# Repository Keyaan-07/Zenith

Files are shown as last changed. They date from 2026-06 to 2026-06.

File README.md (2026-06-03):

# Zenith

Zenith is a small single board computer made with the RK3328 which comes with 512 MegaBytes of DDR3 RAM. Zenith is built to run on battery backups along with USB Type-C power inputs. Features of zenith are:  

- Quad core ARM Cortex-A53 CPU
- 512 MB DDR3 RAM
- SD support
- 100M ethernet
- HDMI out
- 24 bit audio
- 1x USB 3.0 2x USB 2.0

I made this SBC because i wanted to locally host some slack bots. There is literally no other reason. I have not compiled buildroot because i'll be using a prebuilt version from ROCK64. A small reason for this is because my laptop probably cannot handle compiling linux. 

Check out this project on [KiCanvas](https://kicanvas.org/?repo=https%3A%2F%2Fgithub.com%2FKeyaan-07%2FZenith%2Ftree%2Fmain%2Fhardware)!  
To check schematics, please go to the above link, imaging every page and putting it here would clutter the README.

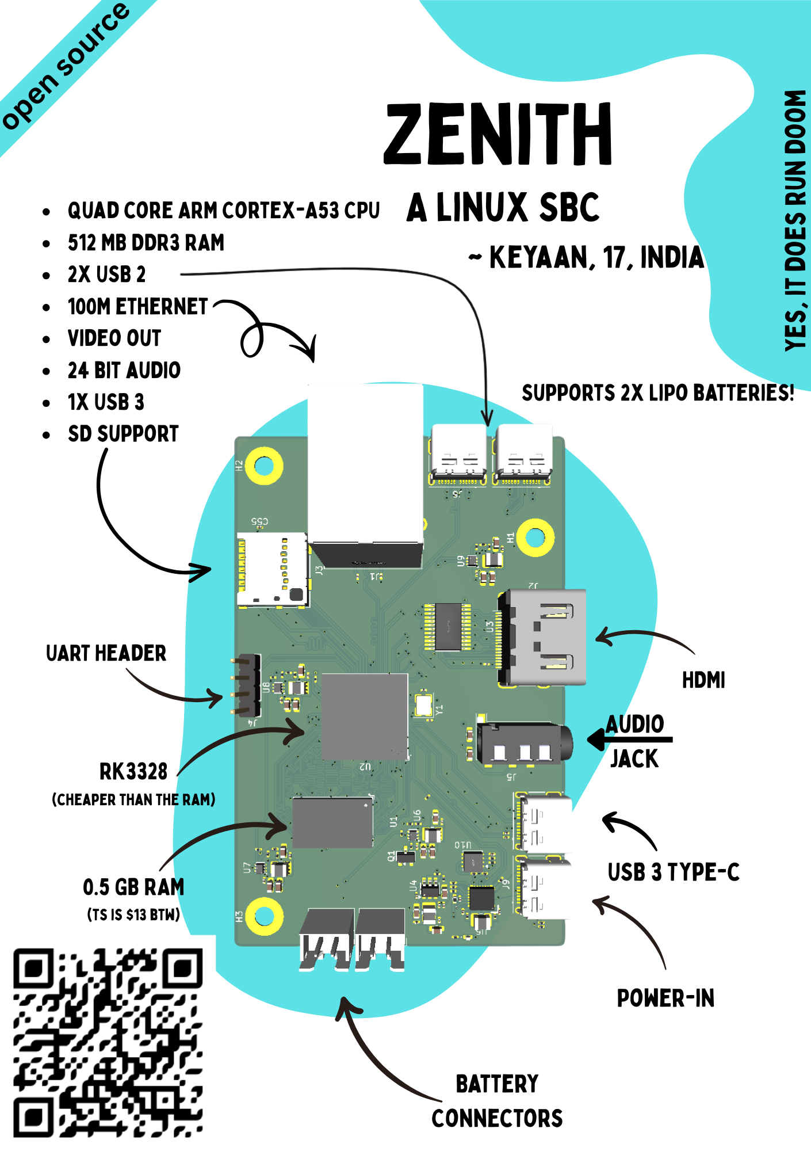
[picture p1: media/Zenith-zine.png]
zine

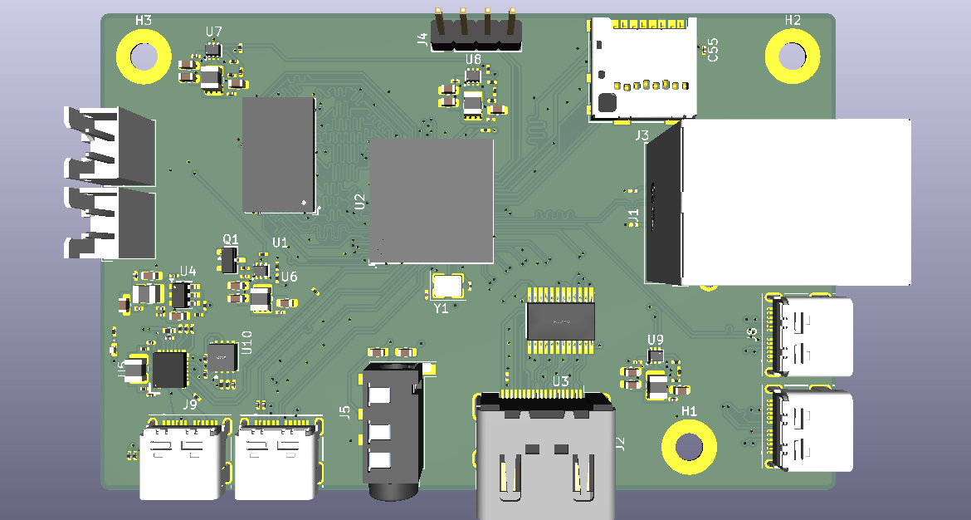
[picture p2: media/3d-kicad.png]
kicad-render

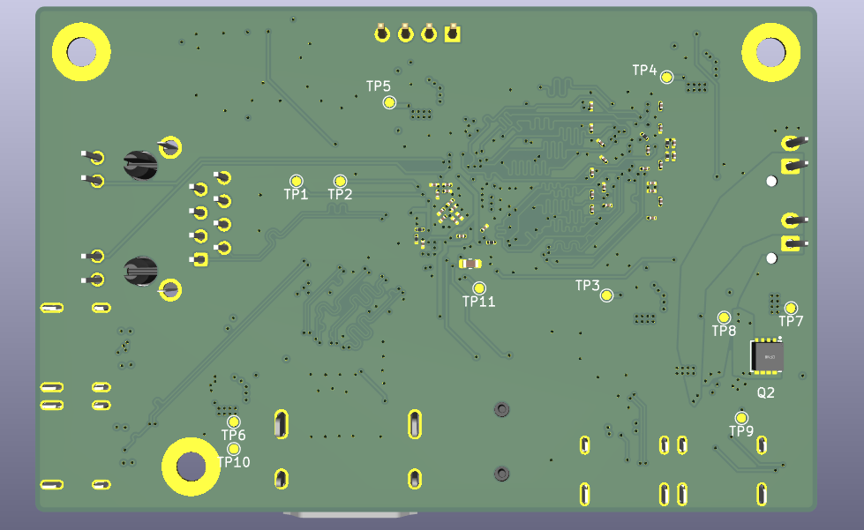
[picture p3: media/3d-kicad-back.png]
kicad-render-back

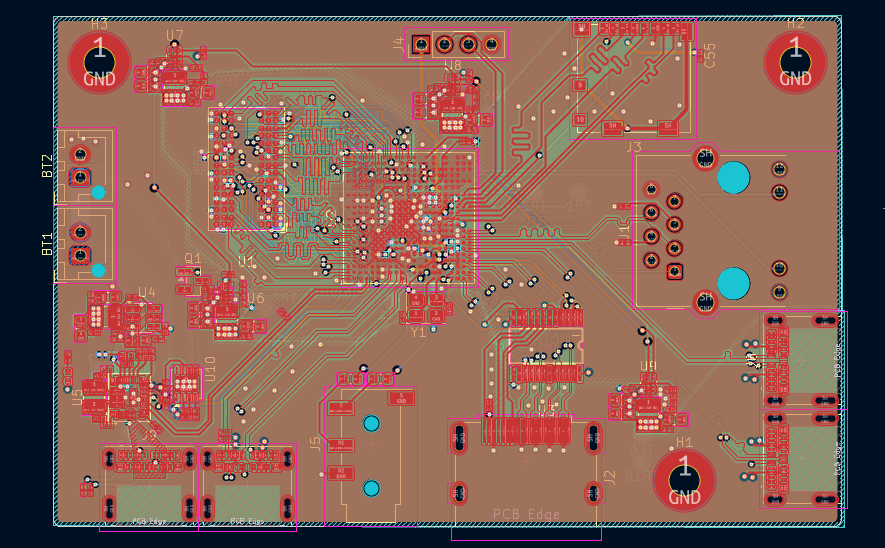
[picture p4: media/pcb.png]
kicad


## Assembly guide:  
1. clone the repo and head to production: 
```bash
git clone https://Github.com/Keyaan-07/Zenith
cd Zenith/hardware/production
```
2. go to your preferred PCB manufacturer and upload the gerber files there. 
3. get the PCBA option for both(or one) sides.
4. Build the firmware from the [buildroot](https://github.com/buildroot/buildroot) repo.
5. flash it to the SD card using [rufus.ie](https://rufus.ie)
6. plug the SD card in and start the board. 

# BOM

|Designator |Function |Value |Quantity|Price |Amount  |Link |
|---|---|---|---|---|---|---|
|PCB |PCB |85x55mm |5 |9.6 |48 |https://jlcpcb.com/ |
|PCBA |Standard |PCBA |2 |42.75 |85.5 |https://jlcpcb.com/ |
|BT1, BT2 |Battery Connectors|Battery_Cell |4 | |0 | |
|C0, C1, C10, C11, C12, C13, C14, C15, C16, C17, C18, C19, C2, C21, C22, C23, C24, C25, C26, C27, C28, C29, C3, C30, C31, C32, C33, C35, C37, C4, C40, C42, C47, C48, C5, C51, C52, C53, C54, C55, C58, C6, C62, C64, C67, C7, C70, C71, C74, C75, C8, C9|Capacitor |100n |104 |0.001 |0.104 |https://www.lcsc.com/product-detail/C49062.html |
|C20, C34, C36, C38, C39, C41, C43, C44, C45, C46, C49, C50, C56, C57, C59, C63, C66 |Capacitor |10u |34 |0.03  |1.02 |https://www.lcsc.com/product-detail/C96446.html |
|C60, C61 |Capacitor |15p |4 |0.0013|0.0052  |https://www.lcsc.com/product-detail/C277480.html  |
|C65, C68 |Capacitor |1u |4 |0.009 |0.036 |https://www.lcsc.com/product-detail/C307385.html  |
|C72, C73 |Capacitor |47n |4 |0.0044|0.0176  |https://www.lcsc.com/product-detail/C2930549.html |
|D1 |LED |LED |2 |0.009 |0.018 |https://www.lcsc.com/product-detail/C7496805.html |
|J1 |Ethernet magjack  |- |2 |1.5 |3 |https://www.lcsc.com/product-detail/C12074.html |
|J2 |HDMI |- |2 |1.5 |3 |https://www.lcsc.com/product-detail/C916313.html  |
|J3 |Micro SD Connector|- |2 |0.68  |1.36 |https://www.lcsc.com/product-detail/C585350.html  |
|J4 |UART header |- |2 |DNP |DNP |DNP |
|J5 |Audiojack |- |2 |0.05  |0.1 |https://www.lcsc.com/product-detail/C431535.html  |
|J6, J7, J8, J9 |USB-C |- |8 |0.5 |4 |https://www.lcsc.com/product-detail/C5156605.html |
|L1, L2, L3, L4, L5, L6 |Inductors |2.2u |12 |0.03  |0.36 |https://www.lcsc.com/product-detail/C45385204.html|
|Q1 |MOSFET |2N7002 |2 |0.05  |0.1 |https://www.lcsc.com/product-detail/C81445.html |
|Q2 |MOSFET |AON7262e |2 |0.58  |1.16 |https://www.lcsc.com/product-detail/C176755.html  |
|R1 |Resistor |240 |2 |0.0009|0.0018  |https://www.lcsc.com/product-detail/C270354.html  |
|R11, R17, R2, R26, R27, R3, R30, R31, R32, R33, R35, R38, R40, R5, R6, R8, R9 |Resistor |10k |34 |0.0007|0.0238  |https://www.lcsc.com/product-detail/C7467266.html |
|R12, R41 |Resistor |35k |4 |0.0015|0.006 |https://www.lcsc.com/product-detail/C180320.html  |
|R13, R14, R15, R18, R19, R20 |Resistor |R |12 |- |0 |- |
|R16 |Resistor |56k |2 |0.0008|0.0016  |https://www.lcsc.com/product-detail/C18164325.html|
|R21 |Resistor |10m |2 |0.14  |0.28 |https://www.lcsc.com/product-detail/C6250315.html |
|R22, R23, R24, R25, R34 |Resistor |100 |10 |0.0009|0.009 |https://www.lcsc.com/product-detail/C270366.html  |
|R28, R29 |Resistor |0R |4 |0.0009|0.0036  |https://www.lcsc.com/product-detail/C106228.html  |
|R36, R37, R39 |Resistor |5.1k |6 |0.0007|0.0042  |https://www.lcsc.com/product-detail/C7467269.html |
|R4 |Resistor |6.6k |2 |0.0008|0.0016  |https://www.lcsc.com/product-detail/C423452.html  |
|U1 |RAM |NT5CB256M16ER-FL|2 |13.15 |26.3 |https://www.lcsc.com/product-detail/C2841154.html |
|U10 |SoC |BQ29209DRBR |2 |0.76  |1.52 |https://www.lcsc.com/product-detail/C139352.html  |
|U2 |main IC |RK3328 |2 |8.65  |17.3 |https://www.lcsc.com/product-detail/C2932939.html |
|U3 |ESD IC for HDMI |TPD12S016PWR |2 |0.8382|1.6764  |https://www.lcsc.com/product-detail/C201665.html  |
|U4 |Buck |TPS565201 |2 |0.64  |1.28 |https://www.lcsc.com/product-detail/C327676.html  |
|U5 |Battery charger |BQ25690RBAR |2 |6.3 |12.6 |https://www.lcsc.com/product-detail/C53283868.html|
|U6, U7, U8, U9 |Buck |TPS563252DRLR |8 |1.05  |8.4 |https://www.lcsc.com/product-detail/C19188399.html|
|Y1 |Crystal |24MHz |2 |0.58  |1.16 |https://www.lcsc.com/product-detail/C41383245.html|
| | | | | | | |
| | | | | | | |
| | | | | | | |
| | | | | |134.8488| |

### Onshape link
[here](https://cad.onshape.com/documents/332461f2f869658015d1b4b3/w/bc37113696b38b58a706d278/e/a246ca9cc7cf7bf594e6cd93) is the onshape link for the project

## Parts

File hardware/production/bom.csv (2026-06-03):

Designator | Footprint | Quantity | Value | LCSC Part #
BT1, BT2 | JST_XH_B2B-XH-AM_1x02_P2.50mm_Vertical | 2 | Battery_Cell
C0, C1, C10, C11, C12, C13, C14, C15, C16, C17, C18, C19, C2, C21, C22, C23, C24, C25, C26, C27, C28, C29, C3, C30, C31, C32, C33, C35, C37, C4, C40, C42, C47, C48, C5, C51, C52, C53, C54, C55, C58, C6, C62, C64, C67, C7, C70, C71, C74, C75, C8, C9 | 0201 | 52 | 100n
C20, C34, C36, C38, C39, C41, C43, C44, C45, C46, C49, C50, C56, C57, C59, C63, C66 | 0603 | 17 | 10u
C60, C61 | 0201 | 2 | C_Small
C65, C68 | 0201 | 2 | 1u
C69 | 0603 | 1 | 22u
C72, C73 | 0201 | 2 | 47n
D1 | 0402 | 1 | LED
J1 | RJ45_Hanrun_HR911105A_Horizontal | 1 | RJ45_Hanrun_HR911105A_Horizontal
J2 | HDMI_A_Molex_208658-1001_Horizontal | 1 | HDMI_A
J3 | microSD_HC_Molex_104031-0811 | 1 | Micro_SD_Card
J4 | PinHeader_1x04_P2.54mm_Vertical | 1 | Conn_01x04_Pin
J5 | Jack_3.5mm_KoreanHropartsElec_PJ-320D-4A_Horizontal | 1 | AudioJack4
J6, J7, J8, J9 | USB_C_Receptacle_Molex_105450-0101 | 4 | USB_C_Receptacle
L1, L2, L3, L4, L5, L6 | 1008 | 6 | 2.2u
Q1 | SOT-23 | 1 | 2N7002
Q2 | DFN-8_L3.3-W3.3-P0.65-BL | 1 | AON7262e | C176755
R1 | 0201 | 1 | 240
R11, R17, R2, R26, R27, R3, R30, R31, R32, R33, R35, R38, R40, R5, R6, R8, R9 | 0201 | 17 | 10k
R12, R41 | 0201 | 2 | 35k
R13, R14, R15, R18, R19, R20 | 0201 | 6 | R
R16 | 0201 | 1 | 56k
R21 | 0402 | 1 | 10m
R22, R23, R24, R25, R34 | 0201 | 5 | 100
R28, R29 | 0201 | 2 | 0R
R36, R37, R39 | 0201 | 3 | 5.1k
R4 | 0201 | 1 | 6.6k
TP1 | TestPoint_Pad_D1.0mm | 1 | ~{UART0_CTS}
TP10, TP11, TP3, TP4, TP5, TP6, TP7, TP8, TP9 | TestPoint_Pad_D1.0mm | 9 | TestPoint
TP2 | TestPoint_Pad_D1.0mm | 1 | ~{UART0_RST}
U1 | TFBGA-96_L13.0-W8.0-R16-C6-P0.80-TL | 1 | NT5CB256M16ER-FL | C2841154
U10 | VSON-8-1EP_3x3mm_P0.65mm_EP1.6x2.4mm | 1 | BQ29209DRBR | C139352
U2 | TFBGA395_L14.0-W14.0_RK3328 | 1 | RK3328 | C2932939
U3 | TSSOP-24_L7.8-W4.4-P0.65-LS6.4-BL | 1 | TPD12S016PWR | C201665
U4 | SOT-23-6 | 1 | TPS565201
U5 | WQFN-26_L4.0-W3.5_BQ25690RBAR | 1 | BQ25690RBAR | C53283868
U6, U7, U8, U9 | SOT-563-6_L1.6-W1.2-P0.50-LS1.6-BL | 4 | TPS563252DRLR | C19188399
Y1 | Crystal_SMD_3225-4Pin_3.2x2.5mm | 1 | Crystal_GND24

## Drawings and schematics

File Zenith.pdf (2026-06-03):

# Zenith

# A linux SBC

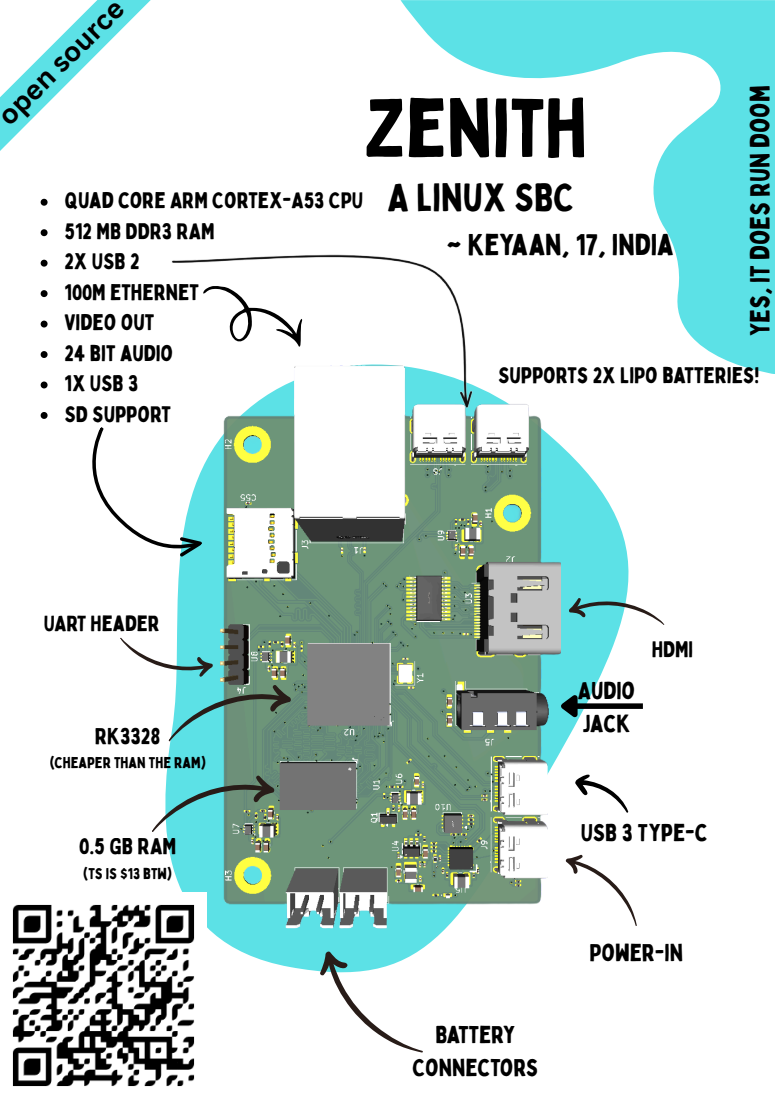
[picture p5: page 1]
Audio jack; ~ Keyaan, 17, india; open source; Battery Connectors; Power-in; USB 3 Type-c; UART Header; HDMI

Quad core ARM Cortex-A53 CPU
512 MB DDR3 RAM
2x USB 2
100M ethernet
Video out
24 bit audio
1x USB 3
SD support

Supports 2x LiPo batteries!

(cheaper than the ram)

0.5 GB RAM
(ts is $13 btw)

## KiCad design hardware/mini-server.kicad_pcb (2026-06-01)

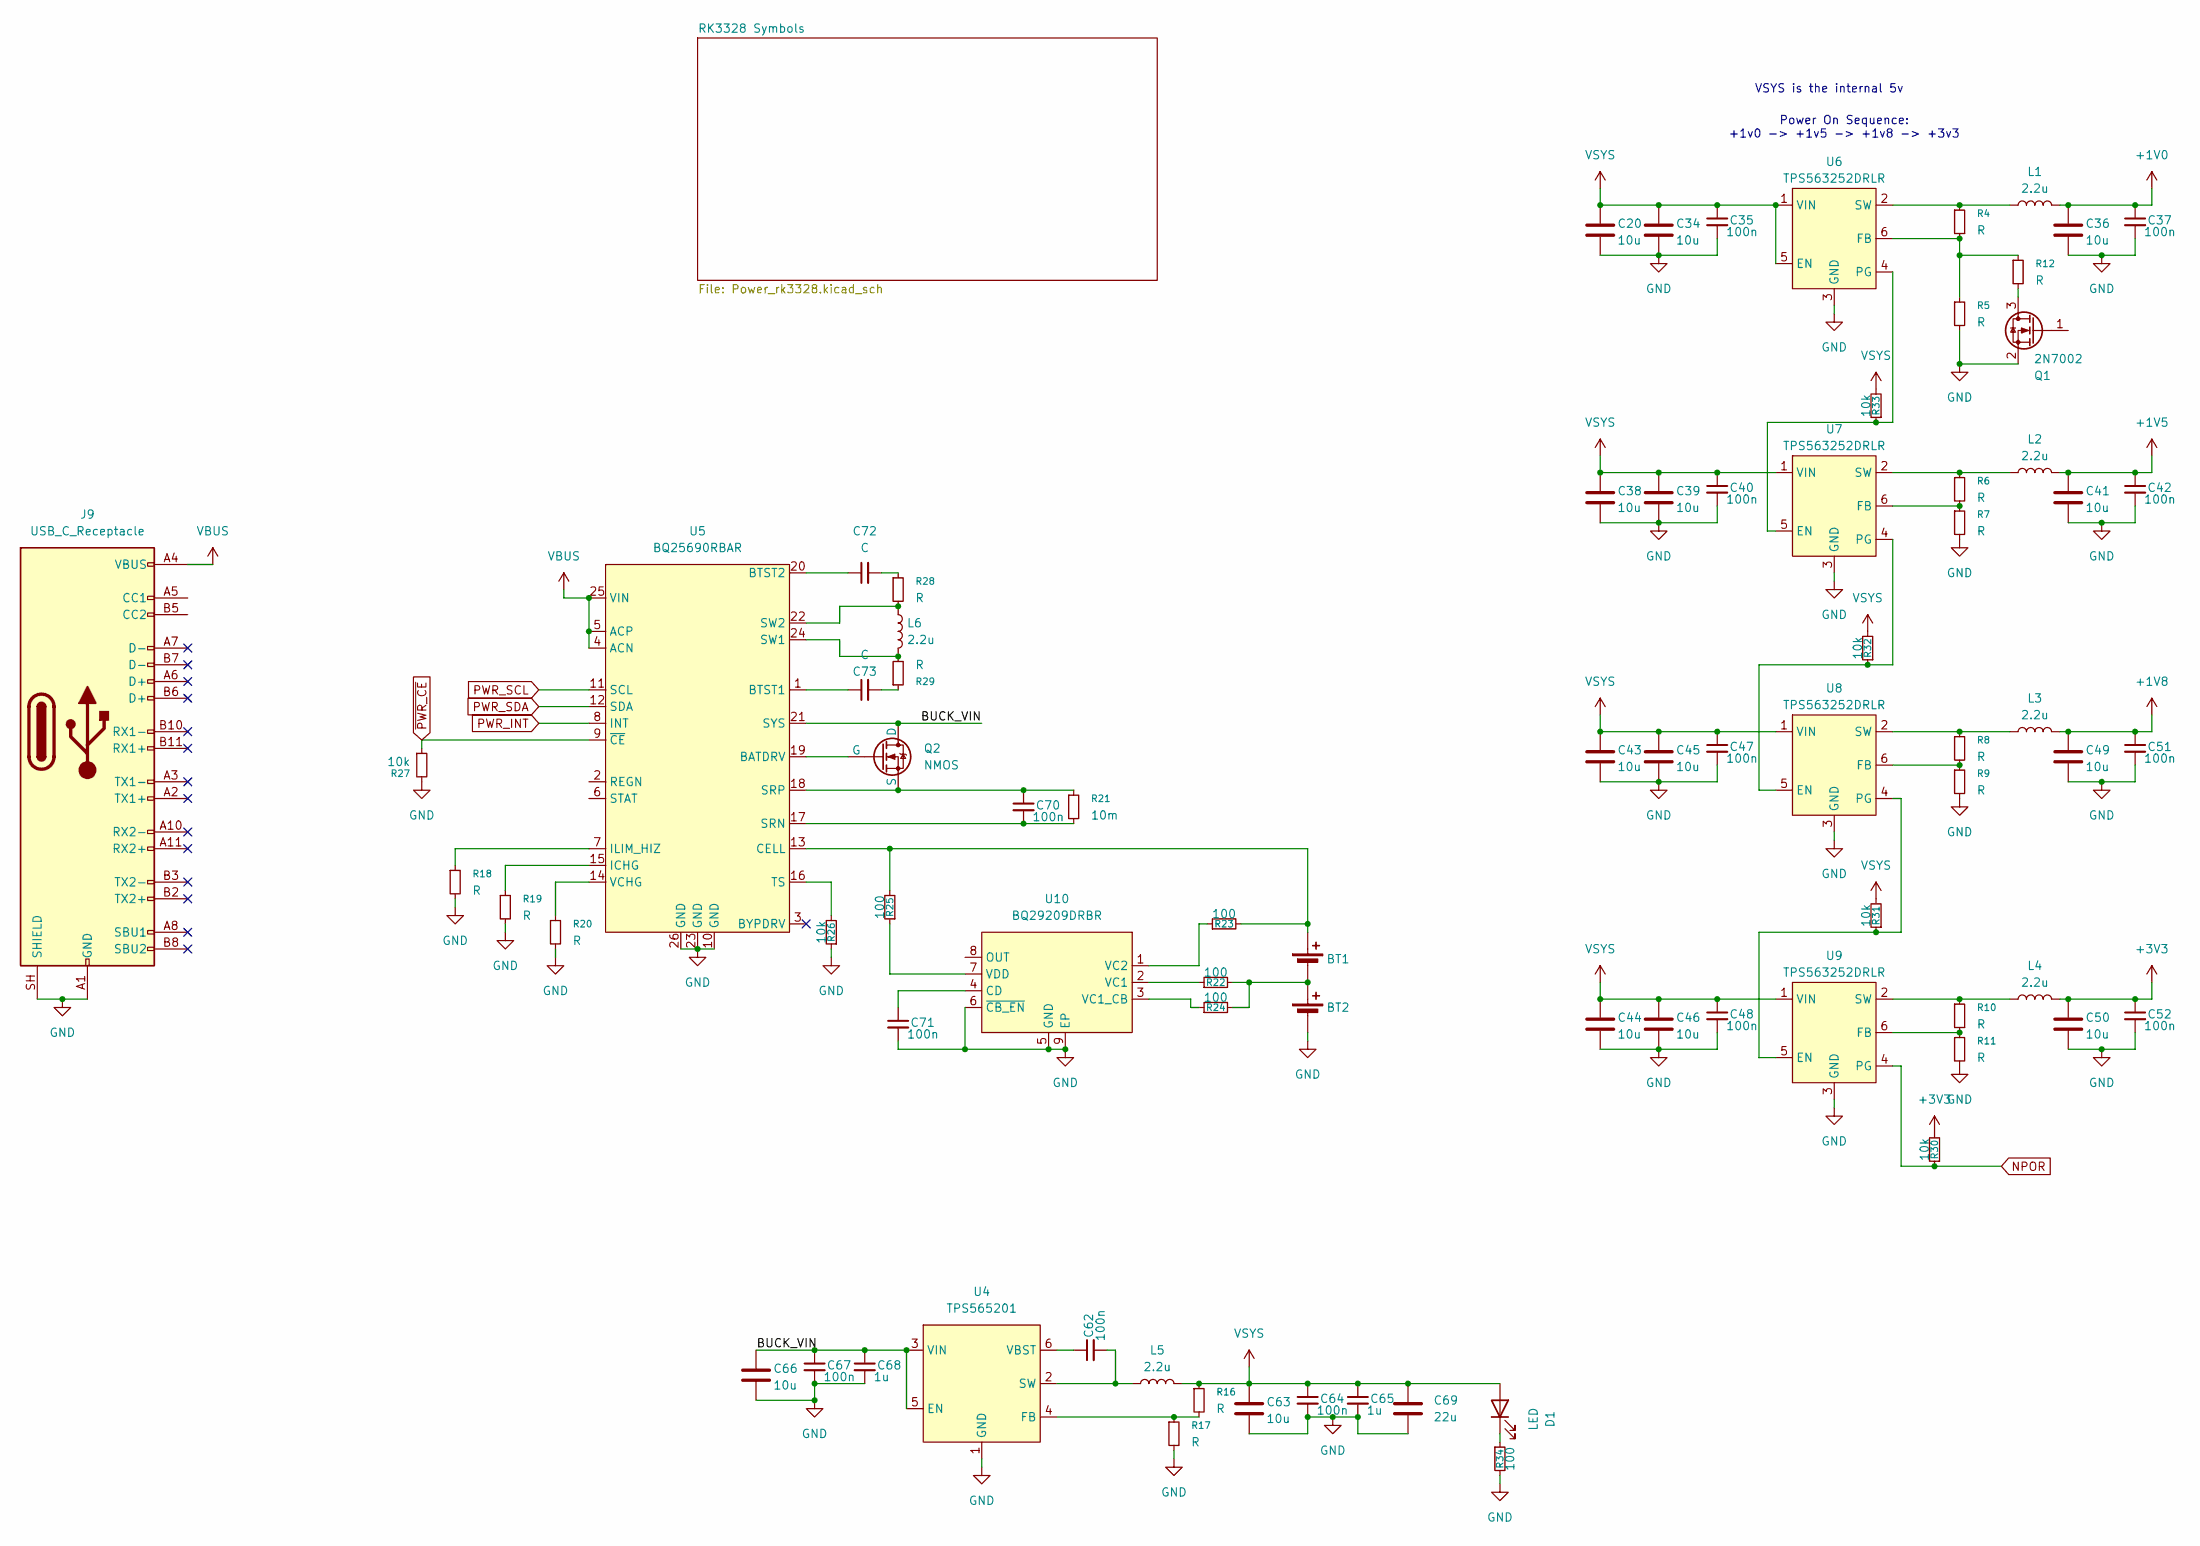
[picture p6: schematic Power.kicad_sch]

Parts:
BT1, BT2: Battery_Cell; JST_XH_B2B-XH-AM_1x02_P2.50mm_Vertical
C20, C34, C36, C38, C39, C41, C43, C44, C45, C46, C49, C50, C63, C66: 10u; C_0603_1608Metric
C35, C37, C40, C42, C47, C48, C51, C52, C62, C64, C67, C70, C71: 100n; C_0201_0603Metric
C65, C68: 1u; C_0201_0603Metric
C69: 22u; C_0603_1608Metric
C72, C73: C; C_0201_0603Metric
D1: LED; LED_0402_1005Metric
J9: USB_C_Receptacle; USB_C_Receptacle_Molex_105450-0101
L1, L2, L3, L4, L5, L6: 2.2u; L_1008_2520Metric
Q1: 2N7002; SOT-23
Q2: NMOS
R4, R5, R6, R7, R8, R9, R10, R11, R12, R16, R17, R18, R19, R20, R28, R29: R; R_0201_0603Metric
R21: 10m; R_0402_1005Metric
R22, R23, R24, R25, R34: 100; R_0201_0603Metric
R26, R27, R30, R31, R32, R33: 10k; R_0201_0603Metric
U4: TPS565201; SOT-23-6
U5: BQ25690RBAR; WQFN-26_L4.0-W3.5_BQ25690RBAR; MPN BQ25690RBAR; LCSC Part C53283868
U6, U7, U8, U9: TPS563252DRLR; SOT-563-6_L1.6-W1.2-P0.50-LS1.6-BL; MPN TPS563252DRLR; LCSC Part C19188399
U10: BQ29209DRBR; VSON-8-1EP_3x3mm_P0.65mm_EP1.6x2.4mm; MPN BQ29209DRBR; LCSC Part C139352

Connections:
+1V0: C36.1, C37.1, L1.2; also elsewhere on the board
+1V5: C41.1, C42.1, L2.2; also elsewhere on the board
+1V8: C49.1, C51.1, L3.2; also elsewhere on the board
+3V3: C50.1, C52.1, L4.2, R30.2; also elsewhere on the board
/Power/BUCK_VIN: C66.1, C67.1, C68.1, Q2.1 (D), U4.3 (VIN), U4.5 (EN), U5.21 (SYS)
GND: BT2.2 (-), C20.2, C34.2, C35.2, C36.2, C37.2, C38.2, C39.2, C40.2, C41.2, C42.2, C43.2, C44.2, C45.2, C46.2, C47.2, C48.2, C49.2, C50.2, C51.2, C52.2, C63.2, C64.2, C65.2, C66.2, C67.2, C68.2, C69.2, C71.2, J9.A1 (GND), J9.A12 (GND), J9.B1 (GND), J9.B12 (GND), J9.SH (SHIELD), Q1.2 (S), R5.2, R7.2, R9.2, R11.2, R17.2, R18.2, R19.2, R20.2, R26.1, R27.2, R34.2, U4.1 (GND), U5.10 (GND), U5.23 (GND), U5.26 (GND), U6.3 (GND), U7.3 (GND), U8.3 (GND), U9.3 (GND), U10.5 (GND), U10.6 (~CB_EN), U10.9 (EP); also elsewhere on the board
NPOR: R30.1, U9.4 (PG); also elsewhere on the board
unnamed: BT1.1 (+), R23.2, R25.2, U5.13 (CELL)
unnamed: BT1.2 (-), BT2.1 (+), R22.2, R24.2
unnamed: C72.2, R28.1
unnamed: C73.2, R29.1
unnamed: D1.1 (K), R34.1
unnamed: Q1.3 (D), R12.2
unnamed: Q2.2 (G), U5.19 (BATDRV)
unnamed: C70.1, Q2.3 (S), R21.1, U5.18 (SRP)
unnamed: R16.2, R17.1, U4.4 (FB)
unnamed: C62.2, L5.1, U4.2 (SW)
unnamed: C62.1, U4.6 (VBST)
unnamed: C73.1, U5.1 (BTST1)
unnamed: C72.1, U5.20 (BTST2)
unnamed: R19.1, U5.15 (ICHG)
unnamed: R18.1, U5.7 (ILIM_HIZ)
unnamed: C70.2, R21.2, U5.17 (SRN)
unnamed: L6.2, R29.2, U5.24 (SW1)
unnamed: L6.1, R28.2, U5.22 (SW2)
unnamed: R26.2, U5.16 (TS)
unnamed: R20.1, U5.14 (VCHG)
unnamed: R4.2, R5.1, R12.1, U6.6 (FB)
unnamed: R33.1, U6.4 (PG), U7.5 (EN)
unnamed: L1.1, R4.1, U6.2 (SW)
unnamed: R6.2, R7.1, U7.6 (FB)
unnamed: R32.1, U7.4 (PG), U8.5 (EN)
unnamed: L2.1, R6.1, U7.2 (SW)
unnamed: R8.2, R9.1, U8.6 (FB)
unnamed: R31.1, U8.4 (PG), U9.5 (EN)
unnamed: L3.1, R8.1, U8.2 (SW)
unnamed: R10.2, R11.1, U9.6 (FB)
unnamed: L4.1, R10.1, U9.2 (SW)
unnamed: C71.1, U10.4 (CD)
unnamed: R22.1, U10.2 (VC1)
unnamed: R24.1, U10.3 (VC1_CB)
unnamed: R23.1, U10.1 (VC2)
unnamed: R25.1, U10.7 (VDD)
PWR_INT: U5.8 (INT); also elsewhere on the board
PWR_SCL: U5.11 (SCL); also elsewhere on the board
PWR_SDA: U5.12 (SDA); also elsewhere on the board
VBUS: J9.A4 (VBUS), J9.A9 (VBUS), J9.B4 (VBUS), J9.B9 (VBUS), U5.4 (ACN), U5.5 (ACP), U5.25 (VIN)
VSYS: C20.1, C34.1, C35.1, C38.1, C39.1, C40.1, C43.1, C44.1, C45.1, C46.1, C47.1, C48.1, C63.1, C64.1, C65.1, C69.1, D1.2 (A), L5.2, R16.1, R31.2, R32.2, R33.2, U6.1 (VIN), U6.5 (EN), U7.1 (VIN), U8.1 (VIN), U9.1 (VIN); also elsewhere on the board
~PWR_CE: R27.1, U5.9 (~CE); also elsewhere on the board

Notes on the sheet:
Power On Sequence: +1v0 -> +1v5 -> +1v8 -> +3v3
VSYS is the internal 5v

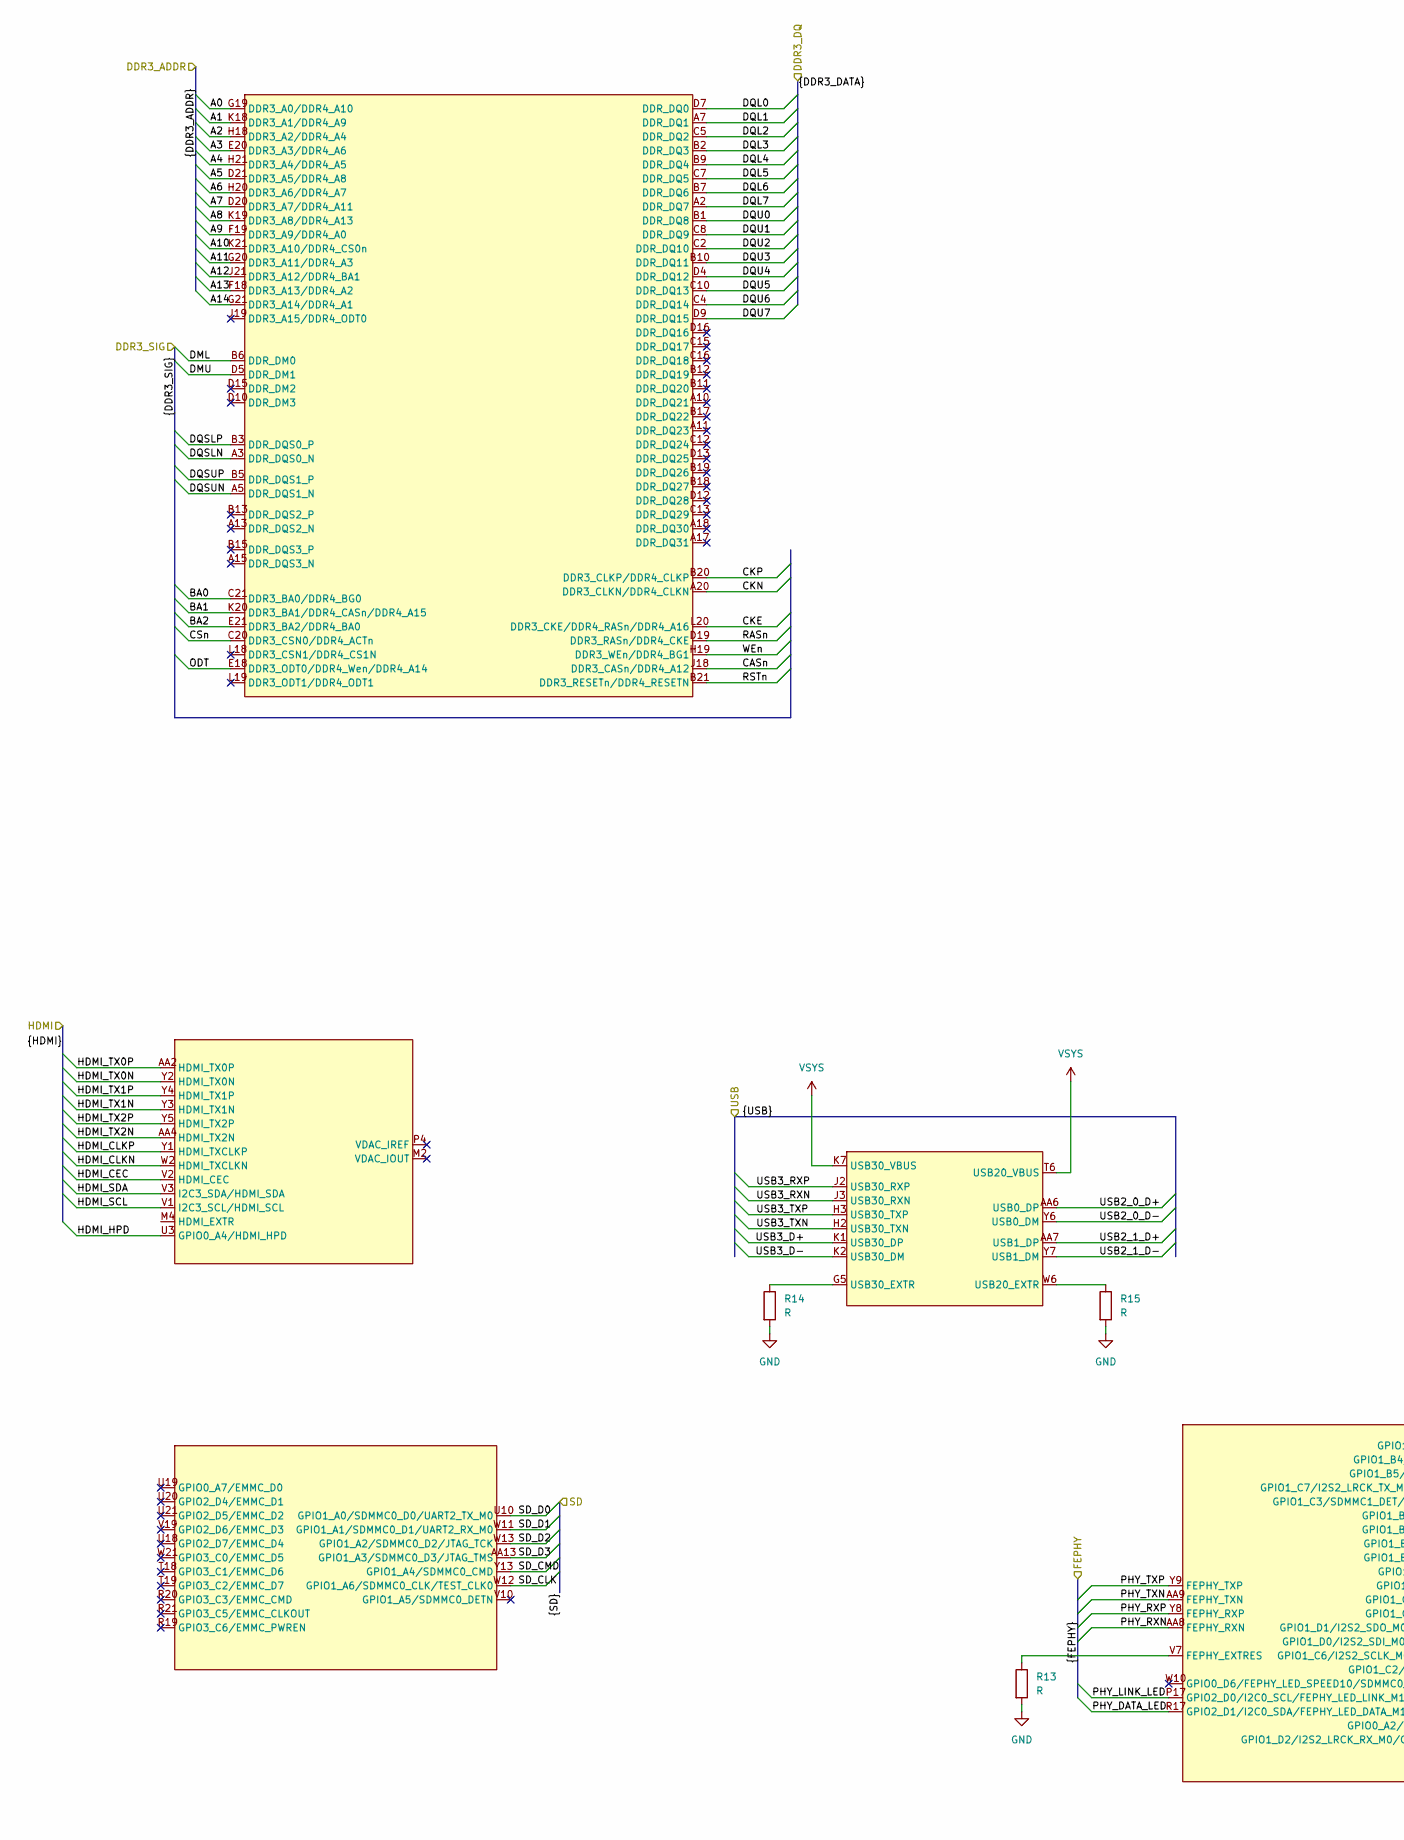
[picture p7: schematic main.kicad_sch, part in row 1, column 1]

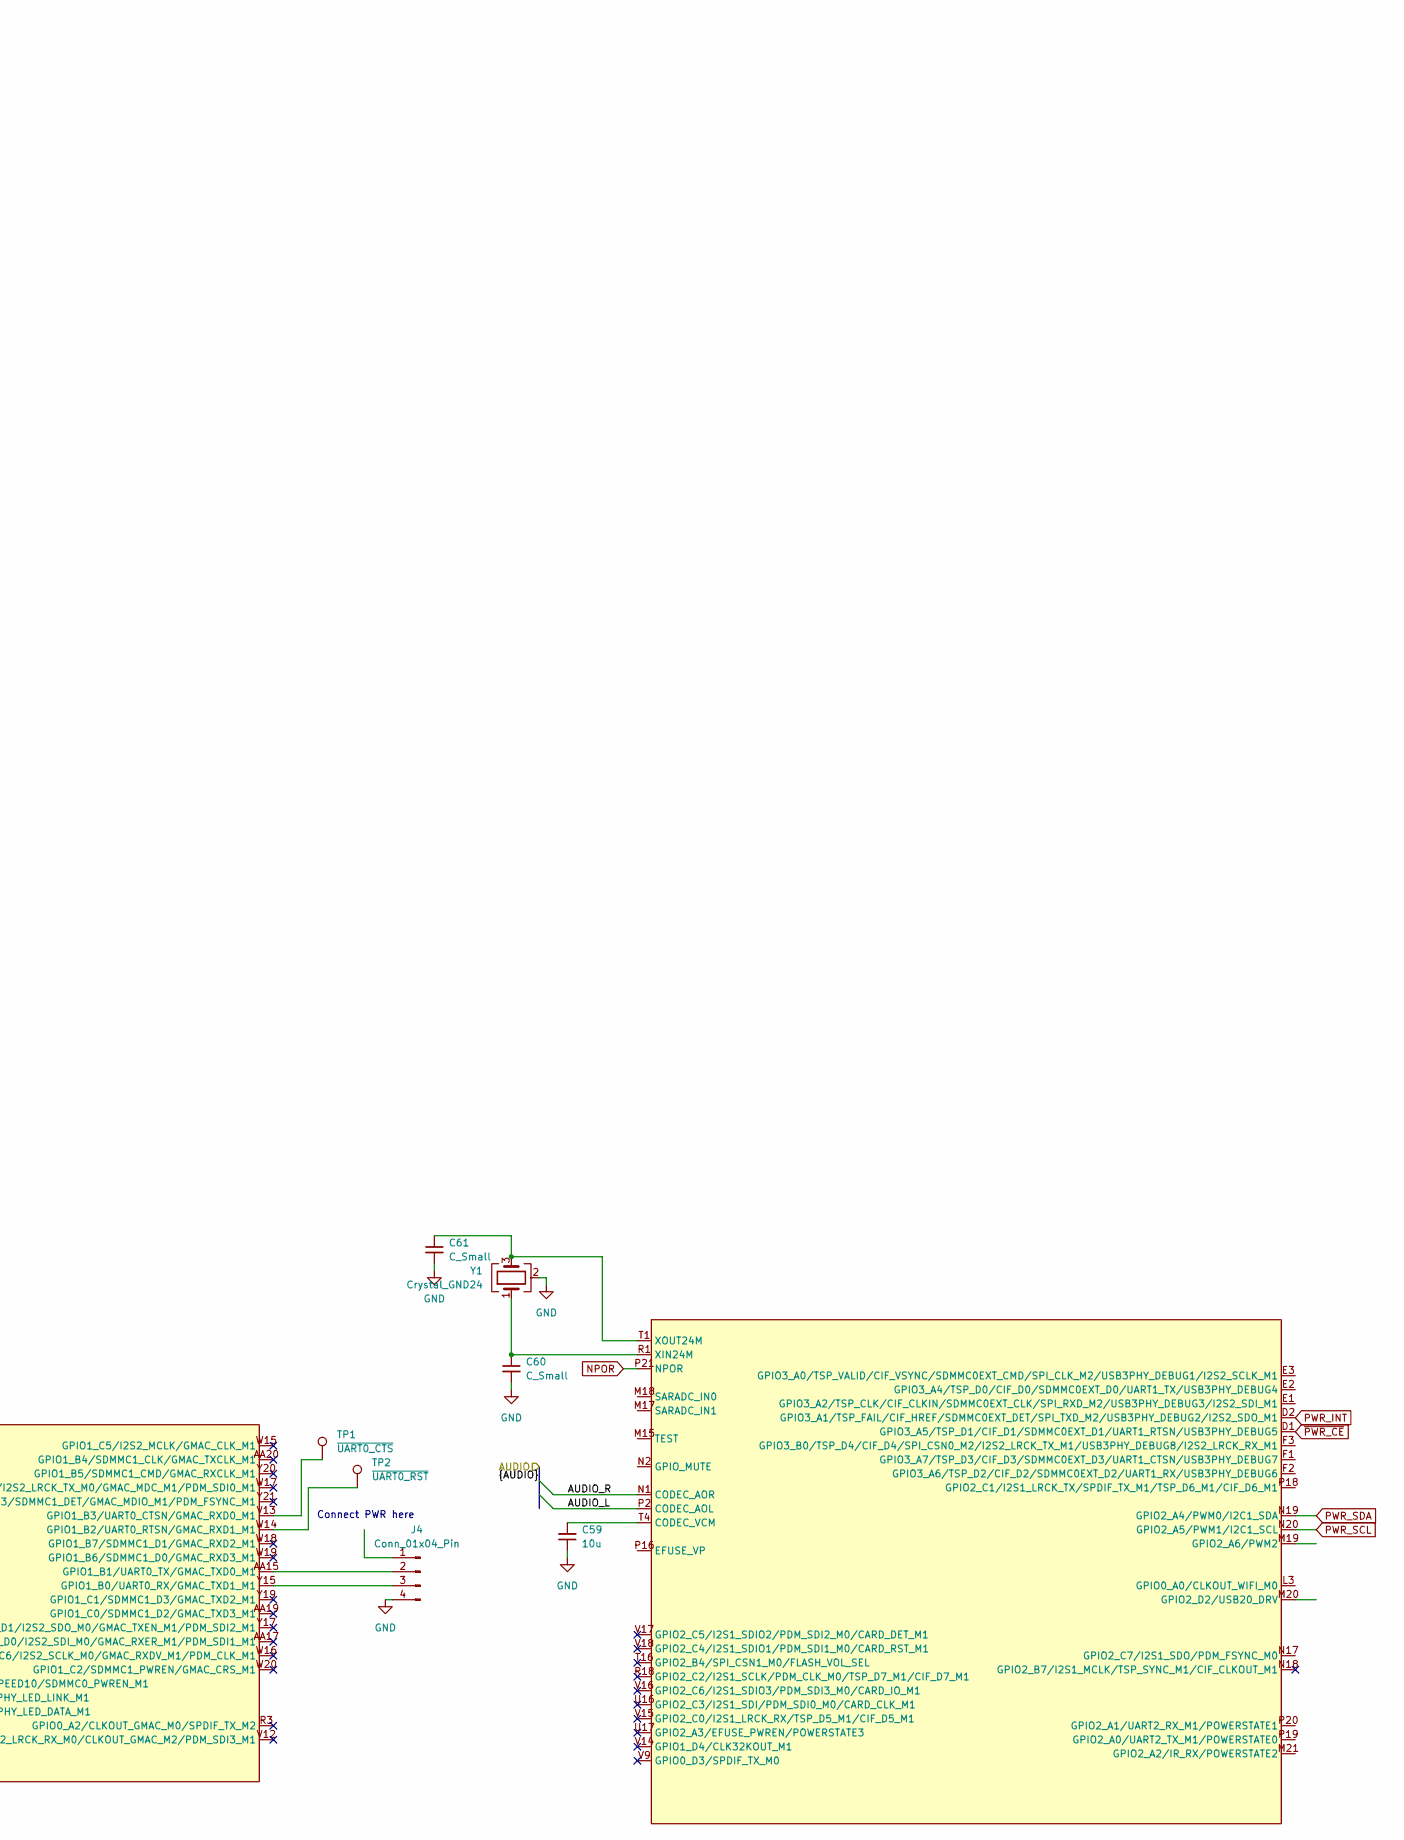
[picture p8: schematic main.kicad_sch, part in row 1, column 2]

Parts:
C59: 10u; C_0603_1608Metric
C60, C61: C_Small; C_0201_0603Metric
J4: Conn_01x04_Pin; PinHeader_1x04_P2.54mm_Vertical
R13, R14, R15: R; R_0201_0603Metric
TP1: ~{UART0_CTS}; TestPoint_Pad_D1.0mm
TP2: ~{UART0_RST}; TestPoint_Pad_D1.0mm
U2: RK3328; TFBGA395_L14.0-W14.0_RK3328; MPN RK3328; LCSC Part C2932939
Y1: Crystal_GND24; Crystal_SMD_3225-4Pin_3.2x2.5mm

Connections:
/Audio/AUDIO_L: U2.P2 (CODEC_AOL); also elsewhere on the board
/Audio/AUDIO_R: U2.N1 (CODEC_AOR); also elsewhere on the board
/DDR3/A0: U2.G19 (DDR3_A0/DDR4_A10); also elsewhere on the board
/DDR3/A1: U2.K18 (DDR3_A1/DDR4_A9); also elsewhere on the board
/DDR3/A2: U2.H18 (DDR3_A2/DDR4_A4); also elsewhere on the board
/DDR3/A3: U2.E20 (DDR3_A3/DDR4_A6); also elsewhere on the board
/DDR3/A4: U2.H21 (DDR3_A4/DDR4_A5); also elsewhere on the board
/DDR3/A5: U2.D21 (DDR3_A5/DDR4_A8); also elsewhere on the board
/DDR3/A6: U2.H20 (DDR3_A6/DDR4_A7); also elsewhere on the board
/DDR3/A7: U2.D20 (DDR3_A7/DDR4_A11); also elsewhere on the board
/DDR3/A8: U2.K19 (DDR3_A8/DDR4_A13); also elsewhere on the board
/DDR3/A9: U2.F19 (DDR3_A9/DDR4_A0); also elsewhere on the board
/DDR3/A10: U2.K21 (DDR3_A10/DDR4_CS0n); also elsewhere on the board
/DDR3/A11: U2.G20 (DDR3_A11/DDR4_A3); also elsewhere on the board
/DDR3/A12: U2.J21 (DDR3_A12/DDR4_BA1); also elsewhere on the board
/DDR3/A13: U2.F18 (DDR3_A13/DDR4_A2); also elsewhere on the board
/DDR3/A14: U2.G21 (DDR3_A14/DDR4_A1); also elsewhere on the board
/DDR3/BA0: U2.C21 (DDR3_BA0/DDR4_BG0); also elsewhere on the board
/DDR3/BA1: U2.K20 (DDR3_BA1/DDR4_CASn/DDR4_A15); also elsewhere on the board
/DDR3/BA2: U2.E21 (DDR3_BA2/DDR4_BA0); also elsewhere on the board
/DDR3/CASn: U2.J18 (DDR3_CASn/DDR4_A12); also elsewhere on the board
/DDR3/CKE: U2.L20 (DDR3_CKE/DDR4_RASn/DDR4_A16); also elsewhere on the board
/DDR3/CKN: U2.A20 (DDR3_CLKN/DDR4_CLKN); also elsewhere on the board
/DDR3/CKP: U2.B20 (DDR3_CLKP/DDR4_CLKP); also elsewhere on the board
/DDR3/CSn: U2.C20 (DDR3_CSN0/DDR4_ACTn); also elsewhere on the board
/DDR3/DML: U2.B6 (DDR_DM0); also elsewhere on the board
/DDR3/DMU: U2.D5 (DDR_DM1); also elsewhere on the board
/DDR3/DQL0: U2.D7 (DDR_DQ0); also elsewhere on the board
/DDR3/DQL1: U2.A7 (DDR_DQ1); also elsewhere on the board
/DDR3/DQL2: U2.C5 (DDR_DQ2); also elsewhere on the board
/DDR3/DQL3: U2.B2 (DDR_DQ3); also elsewhere on the board
/DDR3/DQL4: U2.B9 (DDR_DQ4); also elsewhere on the board
/DDR3/DQL5: U2.C7 (DDR_DQ5); also elsewhere on the board
/DDR3/DQL6: U2.B7 (DDR_DQ6); also elsewhere on the board
/DDR3/DQL7: U2.A2 (DDR_DQ7); also elsewhere on the board
/DDR3/DQSLN: U2.A3 (DDR_DQS0_N); also elsewhere on the board
/DDR3/DQSLP: U2.B3 (DDR_DQS0_P); also elsewhere on the board
/DDR3/DQSUN: U2.A5 (DDR_DQS1_N); also elsewhere on the board
/DDR3/DQSUP: U2.B5 (DDR_DQS1_P); also elsewhere on the board
/DDR3/DQU0: U2.B1 (DDR_DQ8); also elsewhere on the board
/DDR3/DQU1: U2.C8 (DDR_DQ9); also elsewhere on the board
/DDR3/DQU2: U2.C2 (DDR_DQ10); also elsewhere on the board
/DDR3/DQU3: U2.B10 (DDR_DQ11); also elsewhere on the board
/DDR3/DQU4: U2.D4 (DDR_DQ12); also elsewhere on the board
/DDR3/DQU5: U2.C10 (DDR_DQ13); also elsewhere on the board
/DDR3/DQU6: U2.C4 (DDR_DQ14); also elsewhere on the board
/DDR3/DQU7: U2.D9 (DDR_DQ15); also elsewhere on the board
/DDR3/ODT: U2.E18 (DDR3_ODT0/DDR4_Wen/DDR4_A14); also elsewhere on the board
/DDR3/RASn: U2.D19 (DDR3_RASn/DDR4_CKE); also elsewhere on the board
/DDR3/RSTn: U2.B21 (DDR3_RESETn/DDR4_RESETN); also elsewhere on the board
/DDR3/WEn: U2.H19 (DDR3_WEn/DDR4_BG1); also elsewhere on the board
/Ethernet/PHY_DATA_LED: U2.R17 (GPIO2_D1/I2C0_SDA/FEPHY_LED_DATA_M1); also elsewhere on the board
/Ethernet/PHY_LINK_LED: U2.P17 (GPIO2_D0/I2C0_SCL/FEPHY_LED_LINK_M1); also elsewhere on the board
/Ethernet/PHY_RXN: U2.AA8 (FEPHY_RXN); also elsewhere on the board
/Ethernet/PHY_RXP: U2.Y8 (FEPHY_RXP); also elsewhere on the board
/Ethernet/PHY_TXN: U2.AA9 (FEPHY_TXN); also elsewhere on the board
/Ethernet/PHY_TXP: U2.Y9 (FEPHY_TXP); also elsewhere on the board
/HDMI/HDMI_CEC: U2.V2 (HDMI_CEC); also elsewhere on the board
/HDMI/HDMI_CLKN: U2.W2 (HDMI_TXCLKN); also elsewhere on the board
/HDMI/HDMI_CLKP: U2.Y1 (HDMI_TXCLKP); also elsewhere on the board
/HDMI/HDMI_HPD: U2.U3 (GPIO0_A4/HDMI_HPD); also elsewhere on the board
/HDMI/HDMI_SCL: U2.V1 (I2C3_SCL/HDMI_SCL); also elsewhere on the board
/HDMI/HDMI_SDA: U2.V3 (I2C3_SDA/HDMI_SDA); also elsewhere on the board
/HDMI/HDMI_TX0N: U2.Y2 (HDMI_TX0N); also elsewhere on the board
/HDMI/HDMI_TX0P: U2.AA2 (HDMI_TX0P); also elsewhere on the board
/HDMI/HDMI_TX1N: U2.Y3 (HDMI_TX1N); also elsewhere on the board
/HDMI/HDMI_TX1P: U2.Y4 (HDMI_TX1P); also elsewhere on the board
/HDMI/HDMI_TX2N: U2.AA4 (HDMI_TX2N); also elsewhere on the board
/HDMI/HDMI_TX2P: U2.Y5 (HDMI_TX2P); also elsewhere on the board
/Storage/SD_CLK: U2.W12 (GPIO1_A6/SDMMC0_CLK/TEST_CLK0); also elsewhere on the board
/Storage/SD_CMD: U2.Y13 (GPIO1_A4/SDMMC0_CMD); also elsewhere on the board
/Storage/SD_D0: U2.U10 (GPIO1_A0/SDMMC0_D0/UART2_TX_M0); also elsewhere on the board
/Storage/SD_D1: U2.W11 (GPIO1_A1/SDMMC0_D1/UART2_RX_M0); also elsewhere on the board
/Storage/SD_D2: U2.W13 (GPIO1_A2/SDMMC0_D2/JTAG_TCK); also elsewhere on the board
/Storage/SD_D3: U2.AA13 (GPIO1_A3/SDMMC0_D3/JTAG_TMS); also elsewhere on the board
/USB/USB2_0_D+: U2.AA6 (USB0_DP); also elsewhere on the board
/USB/USB2_0_D-: U2.Y6 (USB0_DM); also elsewhere on the board
/USB/USB2_1_D+: U2.AA7 (USB1_DP); also elsewhere on the board
/USB/USB2_1_D-: U2.Y7 (USB1_DM); also elsewhere on the board
/USB/USB3_D+: U2.K1 (USB30_DP); also elsewhere on the board
/USB/USB3_D-: U2.K2 (USB30_DM); also elsewhere on the board
/USB/USB3_RXN: U2.J3 (USB30_RXN); also elsewhere on the board
/USB/USB3_RXP: U2.J2 (USB30_RXP); also elsewhere on the board
/USB/USB3_TXN: U2.H2 (USB30_TXN); also elsewhere on the board
/USB/USB3_TXP: U2.H3 (USB30_TXP); also elsewhere on the board
GND: C59.1, C60.2, C61.2, J4.4, R13.2, R14.2, R15.2, Y1.2 (G), Y1.4 (G); also elsewhere on the board
NPOR: U2.P21 (NPOR); also elsewhere on the board
unnamed: J4.2, U2.AA15 (GPIO1_B1/UART0_TX/GMAC_TXD0_M1)
unnamed: J4.3, U2.Y15 (GPIO1_B0/UART0_RX/GMAC_TXD1_M1)
unnamed: R13.1, U2.V7 (FEPHY_EXTRES)
unnamed: TP2.1 (1_1), U2.W14 (GPIO1_B2/UART0_RTSN/GMAC_RXD1_M1)
unnamed: TP1.1 (1_1), U2.V13 (GPIO1_B3/UART0_CTSN/GMAC_RXD0_M1)
unnamed: R15.1, U2.W6 (USB20_EXTR)
unnamed: R14.1, U2.G5 (USB30_EXTR)
unnamed: C59.2, U2.T4 (CODEC_VCM)
unnamed: C60.1, U2.R1 (XIN24M), Y1.1
unnamed: C61.1, U2.T1 (XOUT24M), Y1.3
PWR_INT: U2.D2 (GPIO3_A1/TSP_FAIL/CIF_HREF/SDMMC0EXT_DE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); also elsewhere on the board
PWR_SCL: U2.N20 (GPIO2_A5/PWM1/I2C1_SCL); also elsewhere on the board
PWR_SDA: U2.N19 (GPIO2_A4/PWM0/I2C1_SDA); also elsewhere on the board
VSYS: U2.K7 (USB30_VBUS), U2.T6 (USB20_VBUS); also elsewhere on the board
~PWR_CE: U2.D1 (GPIO3_A5/TSP_D1/CIF_D1/SDMMC0EXT_D1/UAR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); also elsewhere on the board

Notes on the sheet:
Connect PWR here

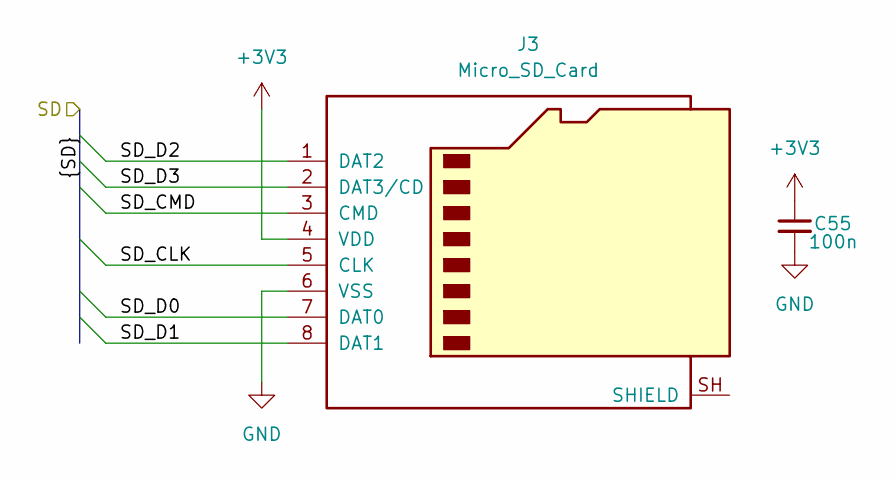
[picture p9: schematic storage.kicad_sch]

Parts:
C55: 100n; C_0201_0603Metric
J3: Micro_SD_Card; microSD_HC_Molex_104031-0811

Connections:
+3V3: C55.1, J3.4 (VDD); also elsewhere on the board
/Storage/SD_CLK: J3.5 (CLK); also elsewhere on the board
/Storage/SD_CMD: J3.3 (CMD); also elsewhere on the board
/Storage/SD_D0: J3.7 (DAT0); also elsewhere on the board
/Storage/SD_D1: J3.8 (DAT1); also elsewhere on the board
/Storage/SD_D2: J3.1 (DAT2); also elsewhere on the board
/Storage/SD_D3: J3.2 (DAT3/CD); also elsewhere on the board
GND: C55.2, J3.6 (VSS); also elsewhere on the board

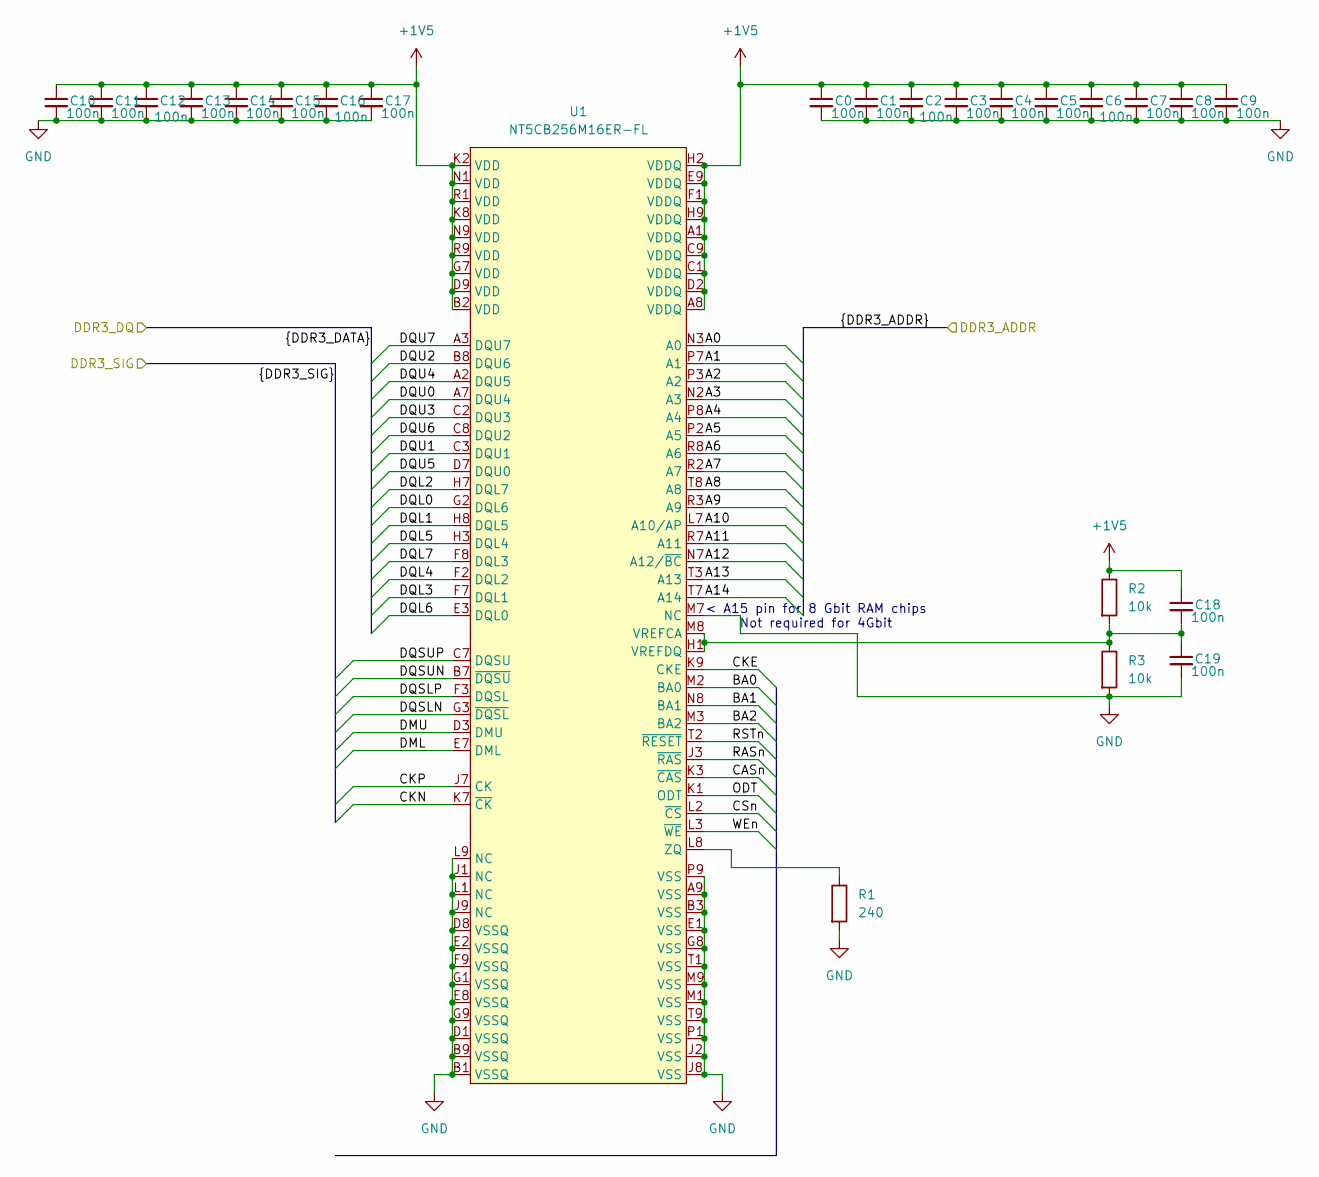
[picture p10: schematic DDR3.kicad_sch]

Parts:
C0, C1, C2, C3, C4, C5, C6, C7, C8, C9, C10, C11, C12, C13, C14, C15, C16, C17, C18, C19: 100n; C_0201_0603Metric
R1: 240; R_0201_0603Metric
R2, R3: 10k; R_0201_0603Metric
U1: NT5CB256M16ER-FL; TFBGA-96_L13.0-W8.0-R16-C6-P0.80-TL; MPN NT5CB256M16ER-FL; LCSC Part C2841154

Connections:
+1V5: C0.1, C1.1, C2.1, C3.1, C4.1, C5.1, C6.1, C7.1, C8.1, C9.1, C10.1, C11.1, C12.1, C13.1, C14.1, C15.1, C16.1, C17.1, C18.1, R2.1, U1.A1 (VDDQ), U1.A8 (VDDQ), U1.B2 (VDD), U1.C1 (VDDQ), U1.C9 (VDDQ), U1.D2 (VDDQ), U1.D9 (VDD), U1.E9 (VDDQ), U1.F1 (VDDQ), U1.G7 (VDD), U1.H2 (VDDQ), U1.H9 (VDDQ), U1.K2 (VDD), U1.K8 (VDD), U1.N1 (VDD), U1.N9 (VDD), U1.R1 (VDD), U1.R9 (VDD); also elsewhere on the board
/DDR3/A0: U1.N3 (A0); also elsewhere on the board
/DDR3/A1: U1.P7 (A1); also elsewhere on the board
/DDR3/A2: U1.P3 (A2); also elsewhere on the board
/DDR3/A3: U1.N2 (A3); also elsewhere on the board
/DDR3/A4: U1.P8 (A4); also elsewhere on the board
/DDR3/A5: U1.P2 (A5); also elsewhere on the board
/DDR3/A6: U1.R8 (A6); also elsewhere on the board
/DDR3/A7: U1.R2 (A7); also elsewhere on the board
/DDR3/A8: U1.T8 (A8); also elsewhere on the board
/DDR3/A9: U1.R3 (A9); also elsewhere on the board
/DDR3/A10: U1.L7 (A10/AP); also elsewhere on the board
/DDR3/A11: U1.R7 (A11); also elsewhere on the board
/DDR3/A12: U1.N7 (A12/~BC); also elsewhere on the board
/DDR3/A13: U1.T3 (A13); also elsewhere on the board
/DDR3/A14: U1.T7 (A14); also elsewhere on the board
/DDR3/BA0: U1.M2 (BA0); also elsewhere on the board
/DDR3/BA1: U1.N8 (BA1); also elsewhere on the board
/DDR3/BA2: U1.M3 (BA2); also elsewhere on the board
/DDR3/CASn: U1.K3 (~CAS); also elsewhere on the board
/DDR3/CKE: U1.K9 (CKE); also elsewhere on the board
/DDR3/CKN: U1.K7 (~CK); also elsewhere on the board
/DDR3/CKP: U1.J7 (CK); also elsewhere on the board
/DDR3/CSn: U1.L2 (~CS); also elsewhere on the board
/DDR3/DML: U1.E7 (DML); also elsewhere on the board
/DDR3/DMU: U1.D3 (DMU); also elsewhere on the board
/DDR3/DQL0: U1.G2 (DQL6); also elsewhere on the board
/DDR3/DQL1: U1.H8 (DQL5); also elsewhere on the board
/DDR3/DQL2: U1.H7 (DQL7); also elsewhere on the board
/DDR3/DQL3: U1.F7 (DQL1); also elsewhere on the board
/DDR3/DQL4: U1.F2 (DQL2); also elsewhere on the board
/DDR3/DQL5: U1.H3 (DQL4); also elsewhere on the board
/DDR3/DQL6: U1.E3 (DQL0); also elsewhere on the board
/DDR3/DQL7: U1.F8 (DQL3); also elsewhere on the board
/DDR3/DQSLN: U1.G3 (~DQSL); also elsewhere on the board
/DDR3/DQSLP: U1.F3 (DQSL); also elsewhere on the board
/DDR3/DQSUN: U1.B7 (~DQSU); also elsewhere on the board
/DDR3/DQSUP: U1.C7 (DQSU); also elsewhere on the board
/DDR3/DQU0: U1.A7 (DQU4); also elsewhere on the board
/DDR3/DQU1: U1.C3 (DQU1); also elsewhere on the board
/DDR3/DQU2: U1.B8 (DQU6); also elsewhere on the board
/DDR3/DQU3: U1.C2 (DQU3); also elsewhere on the board
/DDR3/DQU4: U1.A2 (DQU5); also elsewhere on the board
/DDR3/DQU5: U1.D7 (DQU0); also elsewhere on the board
/DDR3/DQU6: U1.C8 (DQU2); also elsewhere on the board
/DDR3/DQU7: U1.A3 (DQU7); also elsewhere on the board
/DDR3/ODT: U1.K1 (ODT); also elsewhere on the board
/DDR3/RASn: U1.J3 (~RAS); also elsewhere on the board
/DDR3/RSTn: U1.T2 (~RESET); also elsewhere on the board
/DDR3/WEn: U1.L3 (~WE); also elsewhere on the board
GND: C0.2, C1.2, C2.2, C3.2, C4.2, C5.2, C6.2, C7.2, C8.2, C9.2, C10.2, C11.2, C12.2, C13.2, C14.2, C15.2, C16.2, C17.2, C19.2, R1.2, R3.2, U1.A9 (VSS), U1.B1 (VSSQ), U1.B3 (VSS), U1.B9 (VSSQ), U1.D1 (VSSQ), U1.D8 (VSSQ), U1.E1 (VSS), U1.E2 (VSSQ), U1.E8 (VSSQ), U1.F9 (VSSQ), U1.G1 (VSSQ), U1.G8 (VSS), U1.G9 (VSSQ), U1.J1 (NC), U1.J2 (VSS), U1.J8 (VSS), U1.J9 (NC), U1.L1 (NC), U1.L9 (NC), U1.M1 (VSS), U1.M7 (NC), U1.M9 (VSS), U1.P1 (VSS), U1.P9 (VSS), U1.T1 (VSS), U1.T9 (VSS); also elsewhere on the board
unnamed: C18.2, C19.1, R2.2, R3.1, U1.H1 (VREFDQ), U1.M8 (VREFCA)
unnamed: R1.1, U1.L8 (ZQ)

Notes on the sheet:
< A15 pin for 8 Gbit RAM chips Not required for 4Gbit

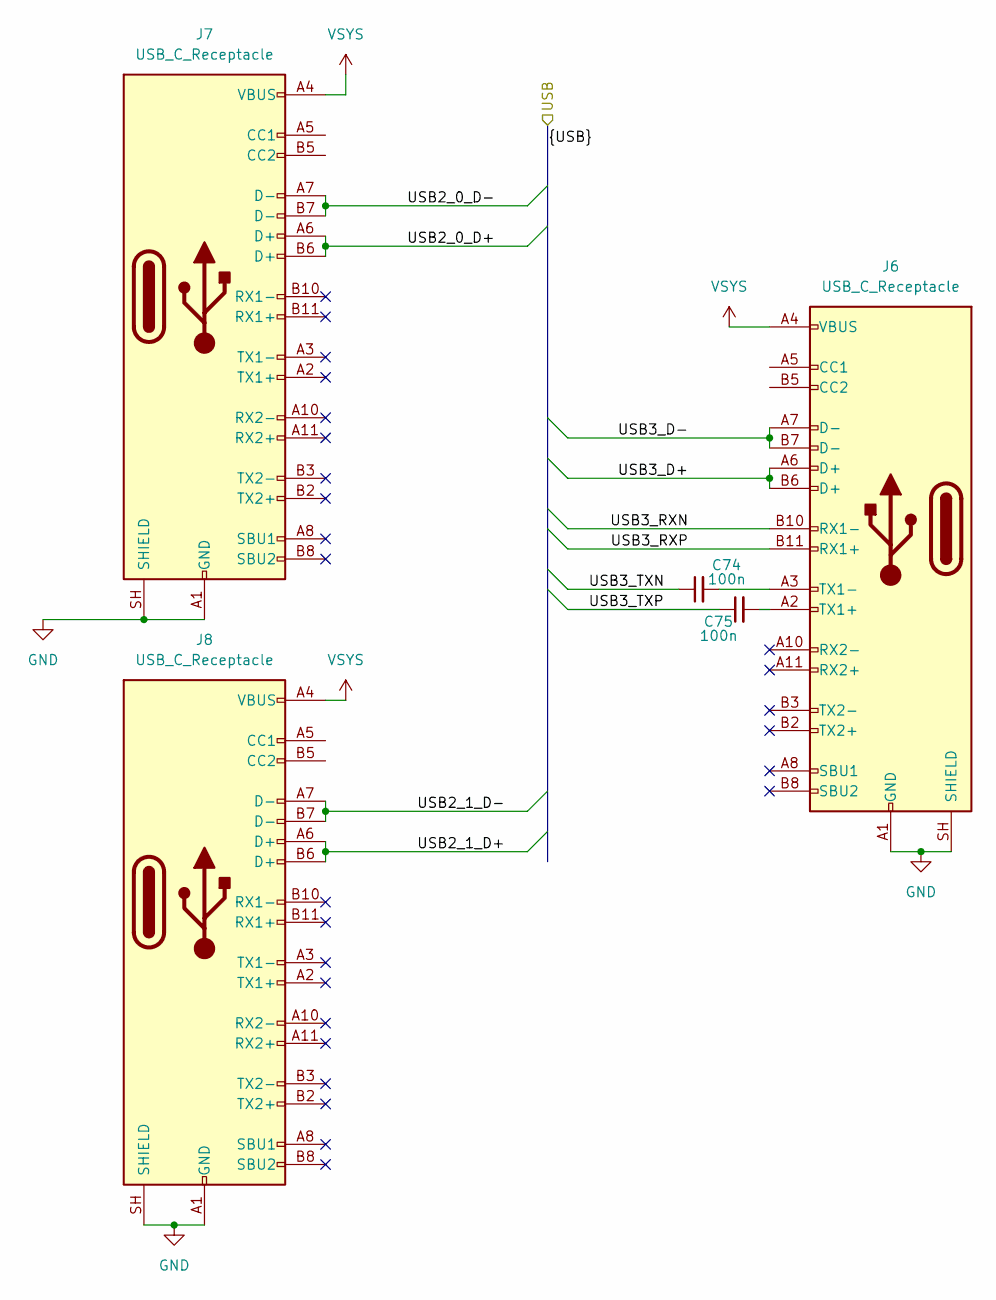
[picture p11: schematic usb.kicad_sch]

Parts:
C74, C75: 100n; C_0201_0603Metric
J6, J7, J8: USB_C_Receptacle; USB_C_Receptacle_Molex_105450-0101

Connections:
/USB/USB2_0_D+: J7.A6 (D+), J7.B6 (D+); also elsewhere on the board
/USB/USB2_0_D-: J7.A7 (D-), J7.B7 (D-); also elsewhere on the board
/USB/USB2_1_D+: J8.A6 (D+), J8.B6 (D+); also elsewhere on the board
/USB/USB2_1_D-: J8.A7 (D-), J8.B7 (D-); also elsewhere on the board
/USB/USB3_D+: J6.A6 (D+), J6.B6 (D+); also elsewhere on the board
/USB/USB3_D-: J6.A7 (D-), J6.B7 (D-); also elsewhere on the board
/USB/USB3_RXN: J6.B10 (RX1-); also elsewhere on the board
/USB/USB3_RXP: J6.B11 (RX1+); also elsewhere on the board
/USB/USB3_TXN: C74.1; also elsewhere on the board
/USB/USB3_TXP: C75.1; also elsewhere on the board
GND: J6.A1 (GND), J6.A12 (GND), J6.B1 (GND), J6.B12 (GND), J6.SH (SHIELD), J7.A1 (GND), J7.A12 (GND), J7.B1 (GND), J7.B12 (GND), J7.SH (SHIELD), J8.A1 (GND), J8.A12 (GND), J8.B1 (GND), J8.B12 (GND), J8.SH (SHIELD); also elsewhere on the board
unnamed: C75.2, J6.A2 (TX1+)
unnamed: C74.2, J6.A3 (TX1-)
VSYS: J6.A4 (VBUS), J6.A9 (VBUS), J6.B4 (VBUS), J6.B9 (VBUS), J7.A4 (VBUS), J7.A9 (VBUS), J7.B4 (VBUS), J7.B9 (VBUS), J8.A4 (VBUS), J8.A9 (VBUS), J8.B4 (VBUS), J8.B9 (VBUS); also elsewhere on the board

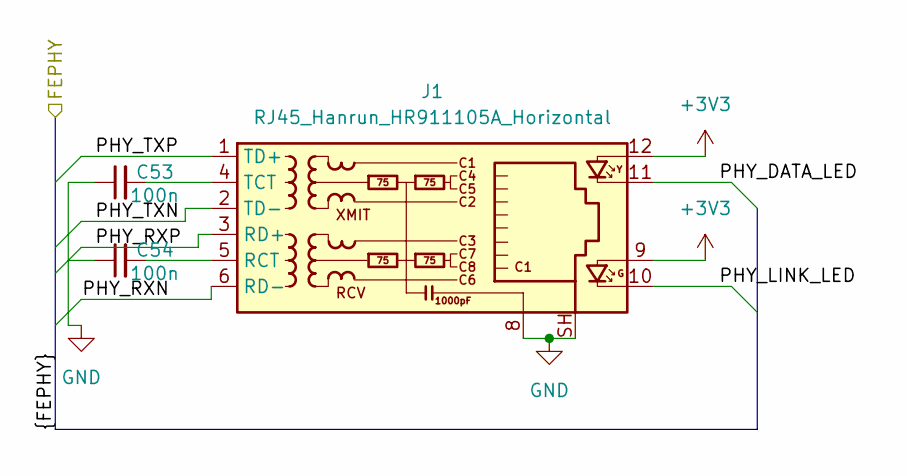
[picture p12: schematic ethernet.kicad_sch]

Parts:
C53, C54: 100n; C_0201_0603Metric
J1: RJ45_Hanrun_HR911105A_Horizontal

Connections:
+3V3: J1.9, J1.12; also elsewhere on the board
/Ethernet/PHY_DATA_LED: J1.11; also elsewhere on the board
/Ethernet/PHY_LINK_LED: J1.10; also elsewhere on the board
/Ethernet/PHY_RXN: J1.6 (RD-); also elsewhere on the board
/Ethernet/PHY_RXP: J1.3 (RD+); also elsewhere on the board
/Ethernet/PHY_TXN: J1.2 (TD-); also elsewhere on the board
/Ethernet/PHY_TXP: J1.1 (TD+); also elsewhere on the board
GND: C53.1, C54.1, J1.8, J1.SH; also elsewhere on the board
unnamed: C54.2, J1.5 (RCT)
unnamed: C53.2, J1.4 (TCT)

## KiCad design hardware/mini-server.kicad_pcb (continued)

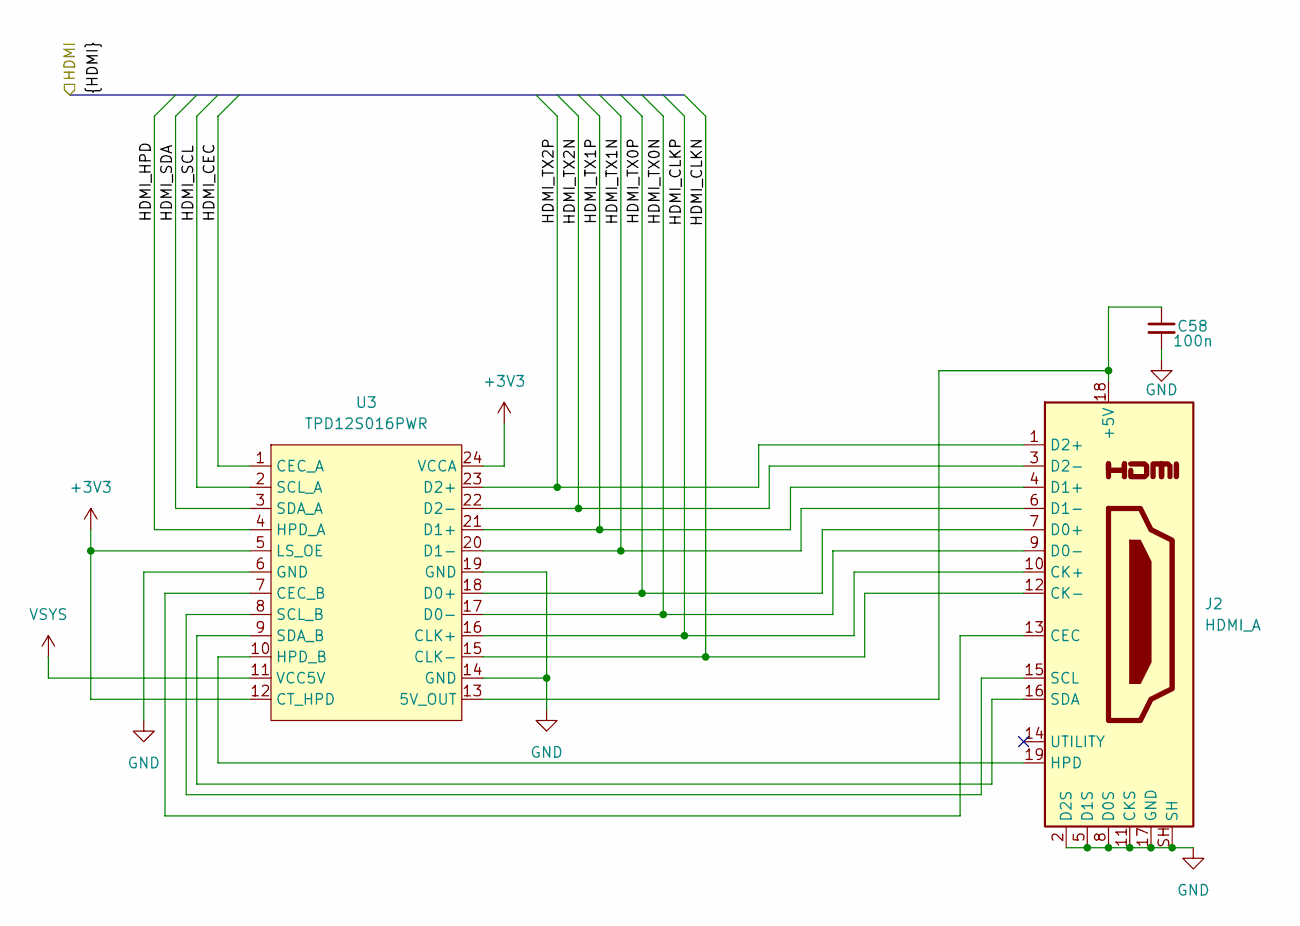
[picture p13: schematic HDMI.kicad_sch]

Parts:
C58: 100n; C_0201_0603Metric
J2: HDMI_A; HDMI_A_Molex_208658-1001_Horizontal
U3: TPD12S016PWR; TSSOP-24_L7.8-W4.4-P0.65-LS6.4-BL; MPN TPD12S016PWR; LCSC Part C201665

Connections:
+3V3: U3.5 (LS_OE), U3.12 (CT_HPD), U3.24 (VCCA); also elsewhere on the board
/HDMI/HDMI_CEC: U3.1 (CEC_A); also elsewhere on the board
/HDMI/HDMI_CLKN: J2.12 (CK-), U3.15 (CLK-); also elsewhere on the board
/HDMI/HDMI_CLKP: J2.10 (CK+), U3.16 (CLK+); also elsewhere on the board
/HDMI/HDMI_HPD: U3.4 (HPD_A); also elsewhere on the board
/HDMI/HDMI_SCL: U3.2 (SCL_A); also elsewhere on the board
/HDMI/HDMI_SDA: U3.3 (SDA_A); also elsewhere on the board
/HDMI/HDMI_TX0N: J2.9 (D0-), U3.17 (D0-); also elsewhere on the board
/HDMI/HDMI_TX0P: J2.7 (D0+), U3.18 (D0+); also elsewhere on the board
/HDMI/HDMI_TX1N: J2.6 (D1-), U3.20 (D1-); also elsewhere on the board
/HDMI/HDMI_TX1P: J2.4 (D1+), U3.21 (D1+); also elsewhere on the board
/HDMI/HDMI_TX2N: J2.3 (D2-), U3.22 (D2-); also elsewhere on the board
/HDMI/HDMI_TX2P: J2.1 (D2+), U3.23 (D2+); also elsewhere on the board
GND: C58.2, J2.2 (D2S), J2.5 (D1S), J2.8 (D0S), J2.11 (CKS), J2.17 (GND), J2.SH, U3.6 (GND), U3.14 (GND), U3.19 (GND); also elsewhere on the board
unnamed: C58.1, J2.18 (+5V), U3.13 (5V_OUT)
unnamed: J2.13 (CEC), U3.7 (CEC_B)
unnamed: J2.19 (HPD), U3.10 (HPD_B)
unnamed: J2.15 (SCL), U3.8 (SCL_B)
unnamed: J2.16 (SDA), U3.9 (SDA_B)
VSYS: U3.11 (VCC5V); also elsewhere on the board

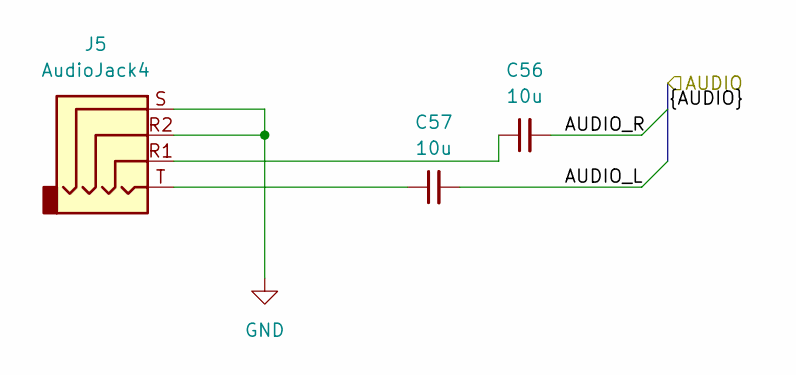
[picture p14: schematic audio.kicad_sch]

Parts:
C56, C57: 10u; C_0603_1608Metric
J5: AudioJack4; Jack_3.5mm_KoreanHropartsElec_PJ-320D-4A_Horizontal

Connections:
/Audio/AUDIO_L: C57.2; also elsewhere on the board
/Audio/AUDIO_R: C56.2; also elsewhere on the board
GND: J5.R2, J5.S; also elsewhere on the board
unnamed: C56.1, J5.R1
unnamed: C57.1, J5.T

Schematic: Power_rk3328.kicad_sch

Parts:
C21, C22, C23, C24, C25, C26, C27, C28, C29, C30, C31, C32, C33: 100n; C_0201_0603Metric
U2: RK3328; TFBGA395_L14.0-W14.0_RK3328; MPN RK3328; LCSC Part C2932939

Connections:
+1V0: C21.1, C22.1, C23.1, C24.1, C25.1, C26.1, C27.1, C28.1, C29.1, C30.1, C31.1, C32.1, C33.1, U2.H7 (PLL_DVDD_1V0), U2.J7 (USB30_DVDD_1V0), U2.M6 (HDMI_AVDD_1V0), U2.N9 (VDD_LOGIC_1), U2.N10 (VDD_LOGIC_2), U2.N11 (VDD_LOGIC_3), U2.P9 (VDD_LOGIC_4), U2.P10 (VDD_LOGIC_5), U2.P11 (VDD_LOGIC_6), U2.P13 (VDD_CORE_1), U2.P14 (VDD_CORE_2), U2.R9 (VDD_LOGIC_7), U2.R10 (VDD_LOGIC_8), U2.R11 (VDD_LOGIC_9), U2.R13 (VDD_CORE_3), U2.R14 (VDD_CORE_4), U2.T13 (VDD_CORE_5), U2.T14 (VDD_CORE_6), U2.T15 (VDD_CORE_7), U2.V5 (USB20_DVDD_1V0), U2.V6 (FEPHY_AVDD_1V0); also elsewhere on the board
+1V5: U2.F10 (VDD_DDRIO_1), U2.F11 (VDD_DDRIO_2), U2.F12 (VDD_DDRIO_3), U2.F13 (VDD_DDRIO_4), U2.G10 (VDD_DDRIO_5), U2.G11 (VDD_DDRIO_6), U2.G12 (VDD_DDRIO_7), U2.G13 (VDD_DDRIO_8), U2.H16 (VDD_DDRIO_9), U2.J15 (VDD_DDRIO_10), U2.J16 (VDD_DDRIO_11), U2.K15 (VDD_DDRIO_12), U2.K16 (VDD_DDRIO_13); also elsewhere on the board
+1V8: U2.H5 (PLL_AVDD_1V8), U2.J5 (USB30_AVDD_1V8), U2.M16 (SARADC_AVDD_1V8), U2.N5 (CODEC_AVDD_1V8), U2.N6 (VDAC_AVDD_1V8), U2.P6 (HDMI_AVDD_1V8), U2.U5 (USB20_AVDD_1V8), U2.U6 (FEPHY_AVDD_1V8); also elsewhere on the board
+3V3: U2.H6 (VCCIO6), U2.J6 (USB30_AVDD_3V3), U2.K6 (VCCIO_PMU), U2.R16 (VCCIO5), U2.T5 (USB20_AVDD_3V3), U2.T7 (VCCIO1), U2.T17 (VCCIO2), U2.U7 (VCCIO3), U2.U12 (VCCIO4); also elsewhere on the board
GND: C21.2, C22.2, C23.2, C24.2, C25.2, C26.2, C27.2, C28.2, C29.2, C30.2, C31.2, C32.2, C33.2, U2.A1 (VSS1), U2.A21 (VSS2), U2.AA1 (VSS151), U2.AA5 (VSS152), U2.AA21 (VSS153), U2.B4 (VSS3), U2.B14 (VSS4), U2.B16 (VSS5), U2.C1 (VSS6), U2.C3 (VSS7), U2.C6 (VSS8), U2.C9 (VSS9), U2.C11 (VSS10), U2.C14 (VSS11), U2.C17 (VSS12), U2.C18 (VSS13), U2.C19 (VSS14), U2.D3 (VSS15), U2.D6 (VSS16), U2.D8 (VSS17), U2.D11 (VSS18), U2.D14 (VSS19), U2.D17 (VSS20), U2.D18 (VSS21), U2.E4 (VSS22), U2.E5 (VSS23), U2.E6 (VSS24), U2.E7 (VSS25), U2.E8 (VSS26), U2.E9 (VSS27), U2.E10 (VSS28), U2.E11 (VSS29), U2.E12 (VSS30), U2.E13 (VSS31), U2.E14 (VSS32), U2.E15 (VSS33), U2.E16 (VSS34), U2.E17 (VSS35), U2.E19 (VSS36), U2.F4 (VSS37), U2.F5 (VSS38), U2.F6 (VSS39), U2.F7 (VSS40), U2.F8 (VSS41), U2.F9 (VSS42), U2.F17 (VSS43), U2.F20 (VSS44), U2.G2 (VSS45), U2.G3 (VSS46), U2.G4 (VSS47), U2.G6 (VSS48), U2.G7 (VSS49), U2.G8 (VSS50), U2.G9 (VSS51), U2.G14 (VSS52), U2.G15 (VSS53), U2.G17 (VSS54), U2.G18 (VSS55), U2.H4 (VSS56), U2.H8 (VSS57), U2.H9 (VSS58), U2.H10 (VSS59), U2.H11 (VSS60), U2.H12 (VSS61), U2.H13 (VSS62), U2.H14 (VSS63), U2.H15 (VSS64), U2.H17 (VSS65), U2.J4 (VSS66), U2.J8 (VSS67), U2.J9 (VSS68), U2.J10 (VSS69), U2.J11 (VSS70), U2.J12 (VSS71), U2.J13 (VSS72), U2.J14 (VSS73), U2.J17 (VSS74), U2.J20 (VSS75), U2.K3 (VSS76), U2.K5 (VSS77), U2.K8 (VSS78), U2.K9 (VSS79), U2.K10 (VSS80), U2.K11 (VSS81), U2.K12 (VSS82), U2.K13 (VSS83), U2.K14 (VSS84), U2.K17 (VSS85), U2.L4 (VSS86), U2.L5 (VSS87), U2.L6 (VSS88), U2.L7 (VSS89), U2.L8 (VSS90), U2.L9 (VSS91), U2.L10 (VSS92), U2.L11 (VSS93), U2.L12 (VSS94), U2.L13 (VSS95), U2.L14 (VSS96), U2.L15 (VSS97), U2.L16 (VSS98), U2.L17 (VSS99), U2.L21 (VSS100), U2.M7 (VSS101), U2.M8 (VSS102), U2.M9 (VSS103), U2.M10 (VSS104), U2.M11 (VSS105), U2.M12 (VSS106), U2.M13 (VSS107), U2.M14 (VSS108), U2.N3 (VSS109), U2.N7 (VSS110), U2.N8 (VSS111), U2.N12 (VSS112), U2.N13 (VSS113), U2.N14 (VSS114), U2.N15 (VSS115), U2.P3 (VSS116), U2.P7 (VSS117), U2.P8 (VSS118), U2.P12 (VSS119), U2.P15 (VSS120), U2.R2 (VSS121), U2.R4 (CODEC_AVSS), U2.R5 (VSS122), U2.R7 (VSS123), U2.R8 (VSS124), U2.R12 (VSS125), U2.R15 (VSS126), U2.T2 (VSS127), U2.T3 (VSS128), U2.T8 (VSS129), U2.T9 (VSS130), U2.T10 (VSS131), U2.T11 (VSS132), U2.T12 (VSS133), U2.U4 (VSS134), U2.U8 (VSS135), U2.U9 (VSS136), U2.U11 (VSS137), U2.U13 (VSS138), U2.U14 (VSS139), U2.U15 (VSS140), U2.V4 (VSS141), U2.V8 (VSS142), U2.V11 (VSS143), U2.W1 (VSS144), U2.W3 (VSS145), U2.W4 (VSS146), U2.W5 (VSS147), U2.W7 (VSS148), U2.W8 (VSS149), U2.W9 (VSS150); also elsewhere on the board

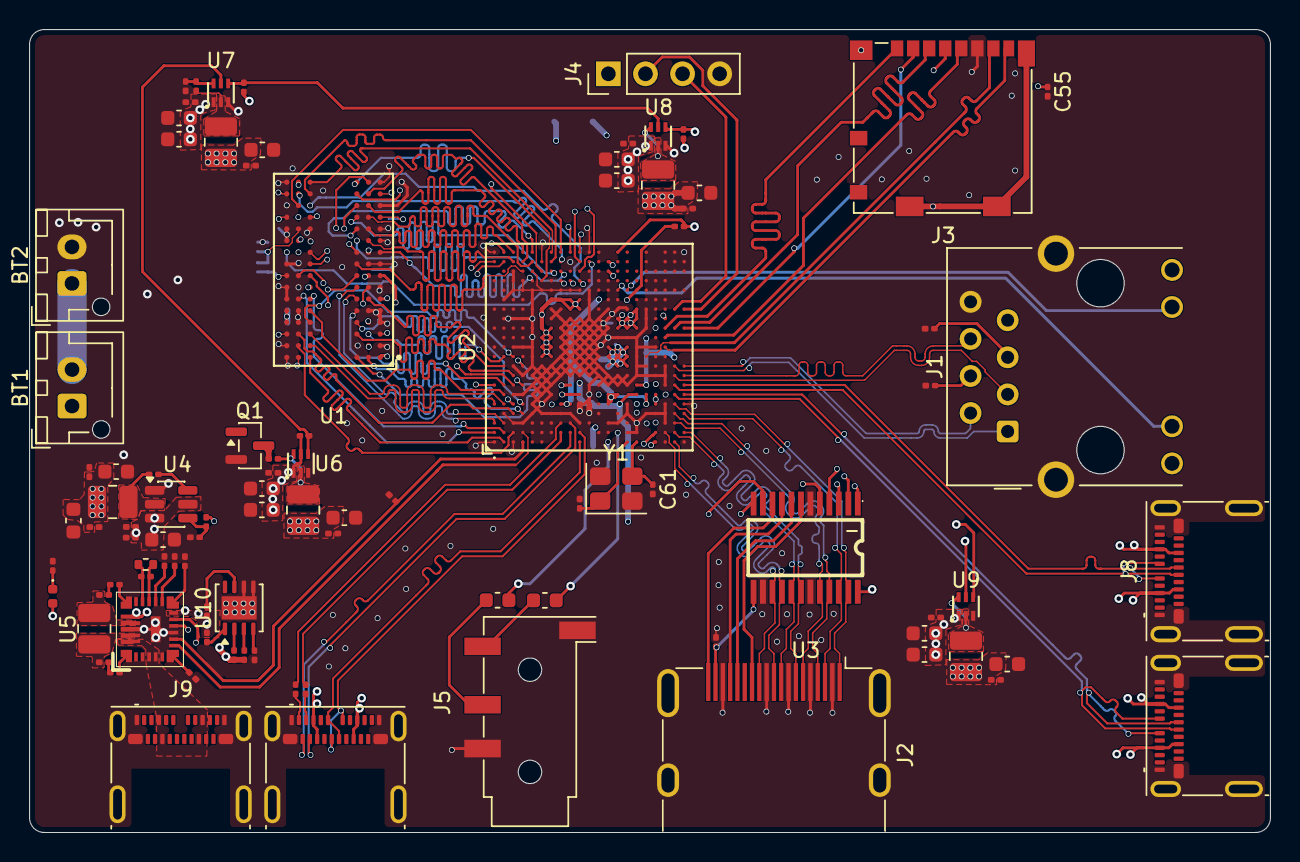
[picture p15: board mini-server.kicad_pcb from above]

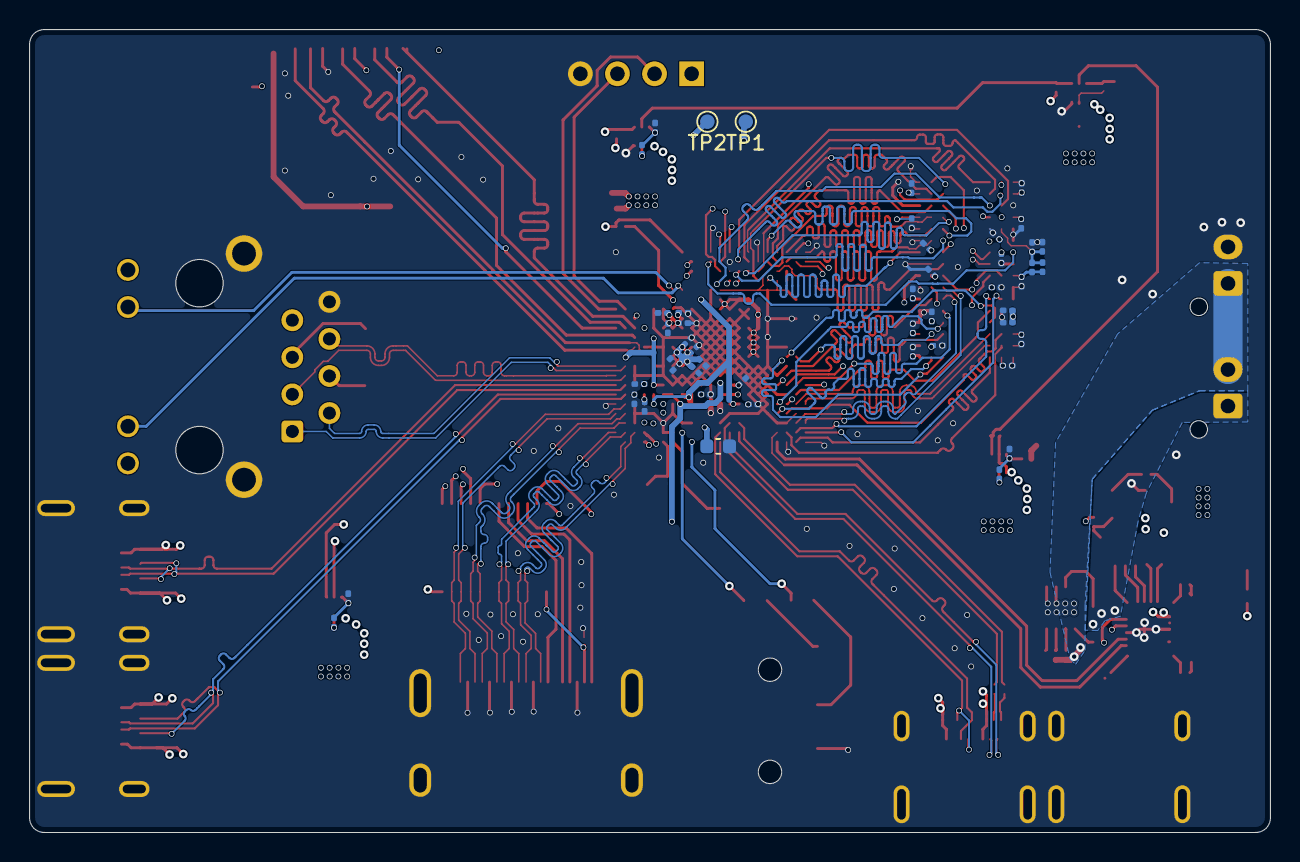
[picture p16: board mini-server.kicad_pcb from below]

Board: 6 copper layers, 85.0 x 55.0 mm, 142 parts (48 on the bottom side), 156 nets.

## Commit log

2026-04-19 hello world
    [mini-server.kicad_pcb, mini-server.kicad_sch]
2026-04-21 Made a new power schematic and a new DDR4 ram schematic
    [DDR4_PHY.kicad_sch, mini-server.kicad_pcb, mini-server.kicad_sch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]
2026-04-22 DDR4 schematic almost completed
    [DDR4_PHY.kicad_sch, core.kicad_sch, mini-server.kicad_pcb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]
2026-05-08 New SoC
    [DDR3.kicad_sch, DDR4_PHY.kicad_sch, core.kicad_sch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]
2026-05-09 Address and Control signals of DDR3 ram routed
    [DDR3.kicad_sch, Power.kicad_sch, main.kicad_sch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]
2026-05-11 DQ lines routed from the RK3328 to DDR3 RAM
    [mini-server.kicad_pcb, root.kicad_sch]
2026-05-16 Routing and PCB
    [DDR3.kicad_sch, HDMI.kicad_sch, Power.kicad_sch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]
2026-05-16 component Placement
    [DDR3.kicad_sch, HDMI.kicad_sch, Power.kicad_sch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]
2026-05-25 New battery charger IC
    [Power.kicad_sch, mini-server.kicad_pcb]
2026-05-29 routing and power pours
    [mini-server.kicad_pcb]
2026-06-01 touch up on lots of small things
    [DDR3.kicad_sch, Power.kicad_sch, main.kicad_sch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]
2026-06-03 final touches
    [Power.kicad_sch, Power_rk3328.kicad_sch, audio.kicad_sch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]
2026-06-03 pcb step file
2026-06-03 PCB step files
2026-06-03 prod files
    [bom.csv, designators.csv, mini-server.kicad_sch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]
2026-06-03 resistor values fixed
    [Power.kicad_sch]
2026-06-03 update readme with BOM data
